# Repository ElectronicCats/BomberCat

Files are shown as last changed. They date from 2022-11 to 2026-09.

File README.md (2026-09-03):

# BomberCat

<p align=center>
<a href="https://github.com/ElectronicCats/BomberCat/wiki">
  
</a>
</p>

<p align=center>
<a href="https://electroniccats.com/store/bombercat/">
  
</a>
<a href="https://github.com/ElectronicCats/BomberCat/wiki">
  
</a>
</p>

<p align=center>
Also available at distributors:
</p>
<p align=center>
<a href="https://labs.ksec.co.uk/product-category/electronic-cat/">

</a>
</p>

BomberCat 💣 is the latest security tool that combines the most common card technologies: NFC technology (Near Field Communication) and magnetic stripe technology used in access control, identification, and banking cards.
Specially created to audit banking terminals, and identify NFC readers and sniffing tools, with this tool you can audit, read, or emulate magnetic stripes and NFC cards.

It also has an ESP32 co-processor with WiFiNINA firmware that allows it to make WiFi connections to use with HTTP or MQTT protocols, which will allow relay and spoofing attacks to be tested over long distances or on local web servers.

### Applications
BomberCat features an RP2040 MCU working along with the PN7150 (a recent generation NFC chip). 
The USB interface is provided by the RP2040 MCU and the NFC functionality is guaranteed by the PN7150.

BomberCat is designed to be intuitive for users. Easy to program using frameworks such as Arduino, Circuitpython, and Micropython.  We have prepared a series of examples with which you can start experimenting, check out the examples folder.

**Card emulation mode:** in which BomberCat behaves as a smart card or a tag. In this mode, BomberCat emulates an NFC tag. It does not initiate communication, it only responds to the NFC reader. 
A typical application of the card emulation mode is how people use NFC on their smartphones to replace several cards, badges, or tags at once (using the same smartphone for RFID access controls, contactless payments, etc). 
However, card emulation mode is not only beneficial for smartphones but any type of portable device.

**Read/Write:** in which BomberCat behaves as an NFC reader/writer. In this mode, BomberCat communicates with a passive tag, an NFC smart card, or an NFC device operating in the card emulation mode. It can read or write to a tag (although reading is a more common use case because tags will often be write-protected). In this mode, BomberCat generates an RF field, while a tag or card only modulates it.

**Magspoof:** for magnetic stripes interaction.
Magspoof mode can emulate magnetic stripe cards by emulating the electromagnetic pulses of this type of card.

## NFCGate relay

BomberCat can act as an [NFCGate](https://github.com/nfcgate/nfcgate)-compatible
**relay** endpoint: it pairs with a second NFCGate peer — another BomberCat or the
NFCGate Android app — through an `nfcgate-server`, relaying NFC APDUs over WiFi/TCP.
This makes a card that is physically in one place appear in front of a reader in
another — the classic test for whether a contactless reader accepts a card that is
not really present.

It ships with two pieces, each in its own repository:

- **Relay firmware** — [`bombercat-firmware`](https://github.com/ElectronicCats/bombercat-firmware),
  a role-selectable (`reader` / `card`) sketch built on the `BomberCatCore` library.
- **`bombercat` control CLI** — [`bombercat-tools`](https://github.com/ElectronicCats/bombercat-tools),
  a Python tool that configures, runs, monitors and captures the relay over
  USB-serial (APDU capture opens straight in Wireshark).

> Relay/spoofing features are for **authorized security audits only** — see the
> Disclaimer below.

## Characteristics:
- Cortex M0+ processor
- USB C 2.0
- NFC Reader, Card, and NFC Forum
- Arduino compatible
- 100% CircuitPython compatible
- UF2 Bootloader
- WIFI (WiFiNINA)
- BLE (ArduinoBLE)
- 1 LED status
- Open Hardware
- MagSpoof coil
- Battery
- RF protocols supported
  - NFCIP-1, NFCIP-2 protocol 
  - ISO/IEC 14443A, ISO/IEC 14443B PICC, NFC Forum T4T modes via host interface
  - NFC Forum T3T via host interface
  - ISO/IEC 14443A, ISO/IEC 14443B PCD designed according to NFC Forum digital protocol T4T platform and ISO-DEP 
  - FeliCa PCD mode
  - MIFARE Classic PCD encryption mechanism (MIFARE Classic 1K/4K)
  - NFC Forum tag 1 to 5 (MIFARE Ultralight, Jewel, Open FeliCa tag, MIFAREDESFire
  - ISO/IEC 15693/ICODE VCD mode 
  - Includes NXP ISO/IEC14443-A and Innovatron ISO/IEC14443-B intellectual property licensing rights

## Requirements

- **Arduino IDE:** version 2.3.3
- **Board Package:** Electronic Cats Mbed OS RP2040 Boards version 2.0.0

 Libraries:
 
  - **PubSubClient:** version 2.8.0
  - **WiFiNINA:** version 1.8.14
  - **Electronic Cats PN7150:** version 2.1.0
  - **SerialCommand:** [Arduino-SerialCommand](https://github.com/kroimon/Arduino-SerialCommand) 

### **Linux Setup Instructions**
If you are using Linux, ensure the BomberCat is properly recognized by running the post-install script located at:

`~/.arduino15/packages/electroniccats/hardware/mbed_rp2040/2.0.0/post_install.sh`

This step is essential to ensure the board can be detected and the firmware uploaded successfully.

## Wiki and Getting Started

[Getting Started in our Wiki](https://github.com/ElectronicCats/BomberCat/wiki)

## Repositories

This repository holds the **hardware** design (KiCad, BOM, mechanical files) and
general project documentation. Firmware and host tooling used to live here but were
split out into their own repositories for better version control and issue tracking:

### Firmware Repository
All BomberCat firmware (NFCGate relay, DetectTags, DetectReaders, magspoof, and more)
lives here:

https://github.com/ElectronicCats/bombercat-firmware

All BomberCat versions are supported in this repository — check which version you own
and select the proper branch to develop, build, or program your board.

### Tools Repository
The `bombercat` control CLI and other Python dev tooling live here:

https://github.com/ElectronicCats/bombercat-tools

## Disclaimer
>[!IMPORTANT]
>BomberCat is a wireless penetration testing tool intended **solely for use in authorized security audits, where such usage is permitted by applicable laws and regulations**. Before utilizing this tool, it is crucial to ensure compliance with all relevant legal requirements and obtain appropriate permissions from the relevant authorities.
>
>The board **does not provide** any means or authorization to utilize credit cards or engage in any financial transactions that are not legally authorized. **Electronic Cats holds no responsibility for any unauthorized use of the tool or any resulting damages**.

-------

## How to contribute 
 Contributions are welcome! 

Please read the document  [**Contribution Manual**](https://github.com/ElectronicCats/electroniccats-cla/blob/main/electroniccats-contribution-manual.md)  which will show you how to contribute your changes to the project.

✨ Thanks to all our [contributors](https://github.com/ElectronicCats/BomberCat/graphs/contributors)! ✨

See [**_Electronic Cats CLA_**](https://github.com/ElectronicCats/electroniccats-cla/blob/main/electroniccats-cla.md) for more information.

See the  [**community code of conduct**](https://github.com/ElectronicCats/electroniccats-cla/blob/main/electroniccats-community-code-of-conduct.md) for a vision of the community we want to build and what we expect from it.
 
### Supported by
 Thanks [Wallee](https://en.wallee.com/) for support this open source project
 
 <a href="https://en.wallee.com/">
  
</a>

## Maintainer

<p align=center>
<a href="https://github.com/sponsors/ElectronicCats">
  
</a>
</p>

Electronic Cats invests time and resources providing this open-source design, please support Electronic Cats and open-source hardware by purchasing products from Electronic Cats!

### License
<p>

</p>

Electronic Cats invests time and resources in providing this open-source design, please support Electronic Cats and open-source hardware by purchasing products from Electronic Cats!

Designed by Electronic Cats.

Firmware released under an GNU AGPL v3.0 license. See the LICENSE file for more information.

Hardware released under an CERN Open Hardware Licence v1.2. See the LICENSE_HARDWARE file for more information.

Electronic Cats is a registered trademark, please do not use if you sell these PCBs.

Jul 2022

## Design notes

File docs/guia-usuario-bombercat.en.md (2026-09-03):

# User Guide — BomberCat for NFC Audits

> **Read this in another language:** [Español](guia-usuario-bombercat.es.md)

---

## A. Introduction and Legal Warning

### What is BomberCat?

**BomberCat** is a security tool that works with contactless cards
(**NFC** — the same ones used for payments, access control, or identification)
and with magnetic stripe. With it, an auditor can **read, emulate, or relay**
a card to check whether a system is vulnerable.

This guide specifically covers the **relay** function: making a card that is
in one place "appear" in front of a reader that is somewhere else, joining the
two ends over WiFi. It is the classic test to demonstrate whether a reader
accepts a card that is not actually present.

> [!WARNING]
> ## ⚠️ LIABILITY NOTICE — READ IT BEFORE USING
>
> **BomberCat is designed EXCLUSIVELY for authorized security audits and
> testing in controlled environments.**
>
> - Use it **only** on systems, cards, and terminals that **belong to you** or
>   for which you have **explicit written permission** from the owner.
> - Using this tool on third-party cards, accounts, access credentials, or
>   terminals without authorization is, in most countries, a **crime**.
>
> > **The user is solely responsible for how they use the device and for any
> > legal, ethical, or other consequences that may arise from its misuse.**
>
> Electronic Cats and the authors of this firmware are **not responsible** for
> any unauthorized use or for the damages arising from it. The device does
> **not** authorize you to use credit cards or to carry out financial
> transactions that are not legally authorized.

**Before each test, make sure you have:**

- [ ] Written authorization from the owner of the system or the card.
- [ ] A defined scope (what is tested, when, and where).
- [ ] A controlled environment, without affecting third-party people or services.

---

## B. Specifications and Modes of Use

### What is always required? (for all three modes)

The relay always joins **two ends** through a small intermediary program
called the **NFCGate server**. One of the ends acts as a **reader** (reads a
real card) and the other as a **card** (presents itself to a terminal). No
matter which mode you choose: you always need these three pieces.

| Piece | What it is for |
|---|---|
| **NFCGate server** | A program that runs on a PC and forwards the data between the two ends. |
| **WiFi network** | The two ends and the server PC must be on the **same WiFi network**. |
| **Two ends** | One in *reader* mode and the other in *card* mode (depending on the chosen mode). |

**One-time installation of the control software (on your PC, only once):**

```sh
cd tools
python3 -m pip install -r requirements.txt   # installs the dependencies
python3 bombercat.py --help                  # checks that it works
```

> On Linux, for the PC to "see" the BomberCat over USB you may need to add
> your user to the `dialout` group:
> `sudo usermod -aG dialout $USER` and log back in.

**Start the NFCGate server (on the PC, before any test):**

```sh
bombercat testserver run              # starts the server, listens on port 5566
```

Leave it running in its own terminal window. Note the **IP address** of that
PC (for example `192.168.1.5`); you will need it to configure the ends.
On Windows/Mac/Linux you can see the IP with `ipconfig` or `ip a`.

> 💡 **On Linux**, the fastest way to find the IP of the computer running the
> server is the `hostname -I` command: it prints the machine's IP address(es)
> directly. The first one is usually the one for your WiFi network (the one
> you will put in `--server`, for example `192.168.1.5`).

**Key concepts that recur in every mode:**

- **Server (`--server`)**: the IP of the PC and the port, for example
  `192.168.1.5:5566`. **Both ends must point to the same server.**
- **Session (`--session`)**: a number from 1 to 255 that pairs the two ends.
  **Both ends must use exactly the same session number.**
- **Role (`--role`)**: `reader` (reads a physical card) or `card` (presents
  itself as a card to a terminal). **One end must be `reader` and the other `card`.**

> ℹ️ **About timing:** a relay transaction typically takes **12–15 seconds**.
> This is normal because of the WiFi + server path; it does not mean something
> is broken. Keep the card and the terminal still during that time.

---

### One-time preparation: flash the relay firmware onto the BomberCat

Every BomberCat you will use as an end (`reader` or `card`) needs the **NFCGate
relay firmware** flashed onto it. This is done **once** per device (or when a new
firmware version is released). If you bought the BomberCat with different firmware,
or you are not sure, follow these steps.

**What you need:**

- The BomberCat connected to your PC over USB-C.
- The [Arduino IDE](https://www.arduino.cc/en/software) 2.x **or** `arduino-cli`.
- The **Electronic Cats Mbed OS RP2040** board package and the **WiFiNINA** and
  **Electronic Cats PN7150** libraries (the Arduino IDE installs them from its
  board and library managers).

**With `arduino-cli` (the fastest way):**

```sh
cd firmware/NFCGate
arduino-cli compile -b electroniccats:mbed_rp2040:bombercat --library ../core .
arduino-cli upload  -b electroniccats:mbed_rp2040:bombercat -p /dev/ttyACM0 .
```

> Replace `/dev/ttyACM0` with your BomberCat's port (on Windows it will be
> something like `COM5`). The WiFiNINA *"architecture may be incompatible"*
> warnings are **normal** on the BomberCat, not an error.

**With the Arduino IDE:** open `firmware/NFCGate/NFCGate.ino`, select the board
**"Electronic Cats BomberCat"** and, so it resolves `#include <BomberCatCore.h>`,
create a link to the `firmware/core` folder inside `~/Arduino/libraries`. Then
click **Upload**.

**Check that it was flashed** (with the control software already installed):

```sh
bombercat device info      # should reply: fw 0.9.7, state idle
```

If it replies with the version and `state idle`, the BomberCat is ready. Repeat
the process on the **second** BomberCat if you are going to use Mode 1.

> The full technical details (pins, libraries, build options) are in
> [`firmware/NFCGate/README.md`](../firmware/NFCGate/README.md).

---

### Mode 1 — BomberCat Reader + BomberCat Card

**Purpose:** the most reliable and recommended mode. Two BomberCats: one reads
a physical card and the other presents it to a terminal, in another location,
over WiFi. Ideal for demonstrating an end-to-end relay without depending on a
phone. *(This mode is validated on hardware.)*

**Minimum requirements:**

- 2 BomberCat devices with the NFCGate relay firmware.
- 1 PC with the NFCGate server running (previous step).
- 1 physical card to read and 1 terminal/reader to test against.
- Everything on the same WiFi network.

**Steps:**

Connect **both** BomberCats over USB to the same PC. Each one gets a number
(`#1`, `#2`); you can see which is which with:

```sh
bombercat device list                # shows the connected BomberCats
bombercat identify -d 1              # blinks the LED of #1 to recognize it
```

1. **Configure the WiFi on both** (use your real network):
   ```sh
   bombercat config wifi -d 1 --ssid MyWiFiNetwork --pass 'mypassword'
   bombercat config wifi -d 2 --ssid MyWiFiNetwork --pass 'mypassword'
   ```
2. **Configure the roles** (one `reader`, the other `card`; **same session**):
   ```sh
   bombercat config nfcgate -d 1 --server 192.168.1.5:5566 --session 42 --role reader
   bombercat config nfcgate -d 2 --server 192.168.1.5:5566 --session 42 --role card
   ```
3. **Place the physical card** on BomberCat #1 (the `reader`).
4. **Start both**:
   ```sh
   bombercat run -d 1
   bombercat run -d 2
   ```
5. **Check that they connected**:
   ```sh
   bombercat status -d 1        # should show a link and a "peer" present
   ```
6. **Bring the terminal close** to BomberCat #2 (the `card`). Wait 12–15 s for
   the transaction to cross.
7. To see the live detail (logs and APDUs) while you test:
   ```sh
   bombercat monitor -d 1
   ```
8. **When finished**, stop both:
   ```sh
   bombercat stop -d 1
   bombercat stop -d 2
   ```

**Safety recommendations for this mode:**

- Keep the physical card **still and firmly resting** on the `reader`
  throughout the test; if it separates, the relay is cut off.
- Verify that both BomberCats are on the **same session**; a different number
  means they will never pair.
- Do not leave the BomberCats running unattended; stop them when done.

---

### Mode 2 — BomberCat Reader + Phone with NFCGate in Card mode

**Purpose:** use an Android phone with the **NFCGate** app as the end that
presents itself to the terminal (*card*/HCE mode), while the BomberCat reads a
physical card.

> [!IMPORTANT]
> ## 🔴 This mode requires a ROOTED phone
>
> Due to an Android limitation, a **normal (non-rooted)** phone **cannot**
> emulate a payment card toward a terminal: its card mode only responds to a
> test card, so the EMV terminal never reaches the app and **no data crosses**.
>
> This mode **only works** with a **rooted** phone that has the **native
> NFCGate module (Xposed / patched `nfcd`)** installed. If your phone is not
> rooted, **use Mode 3 instead** — it does the same thing with the roles
> reversed and works on normal phones.
>
> 📱 **Don't know how to root the phone or set up NFCGate?** Follow the
> [Guide to rooting an Android phone for NFCGate](https://github.com/ElectronicCats/bombercat-tools/blob/main/docs/guia-rooteo-android-nfcgate.en.md)
> (in the `bombercat-tools` repository), which explains step by step how to
> root with Magisk and install the NFCGate module (Zygisk + LSPosed), with
> their corresponding warnings.

**Minimum requirements:**

- 1 BomberCat with the relay firmware (it will be the `reader`).
- 1 **rooted** Android phone with the **NFCGate** app and its native module.
- 1 PC with the NFCGate server running.
- 1 physical card to read and 1 terminal to test against.
- Everything on the same WiFi network.

**Steps:**

1. **Configure the BomberCat as `reader`** (WiFi + server + session):
   ```sh
   bombercat config wifi    --ssid MyWiFiNetwork --pass 'mypassword'
   bombercat config nfcgate --server 192.168.1.5:5566 --session 42 --role reader
   ```
2. **On the phone, open the NFCGate app** and in its network settings enter
   **the same server address** (the PC's IP) and **the same session number** (42).
3. In the app, **choose emulation/card mode** (so the phone acts as the card
   in front of the terminal) and join the session.
4. **Place the physical card** on the BomberCat and start it:
   ```sh
   bombercat run
   bombercat status        # check that the "peer" (the phone) appears
   ```
5. **Bring the terminal close to the phone.** Wait 12–15 s for the transaction
   to cross.
6. **When finished**, `bombercat stop` and stop the relay in the app.

**Safety recommendations for this mode:**

- Confirm that the app shows the relay **active in emulation mode** before
  bringing the terminal close.
- A rooted phone is more vulnerable; use it dedicated to testing, not as your
  personal phone.
- If nothing crosses, it is almost always because the phone **is not rooted**
  or the NFCGate module is not active → switch to **Mode 3**.

---

### Mode 3 — BomberCat Card + Phone with NFCGate in Reader mode

**Purpose:** the equivalent of Mode 2 but **compatible with normal
(non-rooted) phones**. Here the phone acts as the **reader** (reads a physical
card with its NFC) and the BomberCat presents itself as a **card** to the
terminal. This is the recommended way if you want to use a phone.

**Minimum requirements:**

- 1 BomberCat with the relay firmware (it will be the `card`).
- 1 **normal** Android phone with the **NFCGate** app (no root required).
- 1 PC with the NFCGate server running.
- 1 physical card (the phone will read it) and 1 terminal to test against.
- Everything on the same WiFi network.

**Steps:**

1. **Configure the BomberCat as `card`** (WiFi + server + session):
   ```sh
   bombercat config wifi    --ssid MyWiFiNetwork --pass 'mypassword'
   bombercat config nfcgate --server 192.168.1.5:5566 --session 42 --role card
   ```
2. **On the phone, open NFCGate**, enter **the same server address** and **the
   same session number** (42), and **choose reader mode**. Join the session.
3. **Bring the physical card close to the phone** (the phone is the one
   reading it).
4. **Start the BomberCat**:
   ```sh
   bombercat run
   bombercat status        # check that the "peer" (the phone) appears
   ```
5. **Bring the terminal close to the BomberCat.** Wait 12–15 s for the
   transaction to cross. To see the live detail:
   ```sh
   bombercat monitor
   ```
6. **When finished**, `bombercat stop` and stop the relay in the app.

**Safety recommendations for this mode:**

- Keep the physical card **firmly resting on the phone** during the test.
- As in the other modes, verify that **server and session match** on both ends.
- It is the preferred mode for demonstrations with a phone because it does not
  require root.

---

## C. Common Troubleshooting

| Problem | Likely cause | Solution |
|---|---|---|
| **No data crosses between the ends** | Different session on each end, or they point to different servers. | Check that `--session` and `--server` are **identical** on both ends. |
| **`bombercat device list` does not show the BomberCat** | Charge-only USB cable, or missing serial port permission (Linux). | Use a **data** cable; on Linux add your user to the `dialout` group and log back in. |
| **`status` never shows a "peer"** | The other end has not joined, or there is no WiFi. | Confirm that the server is running, that both ends are on the **same WiFi**, and that you started both (`run`). |
| **With the phone in card mode (Mode 2) nothing happens** | The phone **is not rooted** (Android HCE limitation). | Use **Mode 3**, which works on normal phones. |
| **The transaction takes "too long" (10–15 s)** | This is the normal time for the WiFi + server path. | It is not a failure: keep the card and terminal **still** until it finishes. |
| **The relay cuts off midway** | The card separated from the reader, or the WiFi dropped. | Rest the card again; move the devices closer to the router; `run` again. |

---

## D. Glossary of Terms

- **NFC (Near Field Communication):** contactless communication technology at a
  few centimeters. It is what "contactless" payment cards, card-based access,
  and mobile payment use.
- **Card / Emulation (HCE):** making a device **behave like a card** in front
  of a reader. On a phone it is called *HCE* (Host Card Emulation).
- **Reader:** the role of the one that **reads** a card (generates the NFC
  field and asks it questions). The payment terminal is a reader.
- **Terminal / PoS:** the device that charges or validates (for example, a
  store terminal or an access-control reader).
- **Relay:** a technique that **forwards** the conversation between a card and
  a reader that are **in different places**, as if they were together. It is
  what BomberCat does in this guide.
- **Replay:** replaying a previously captured communication. Related, but not
  what this flow does (here the forwarding is **live**).
- **Security audit:** an **authorized** test to find out whether a system is
  vulnerable, with the owner's permission and within an agreed scope.
- **APDU:** each "message" exchanged between card and reader. In the monitor
  you will see them as sequences of bytes in hexadecimal.
- **NFCGate server:** the intermediary program that forwards the data between
  the two ends of the relay over the network.
- **Session:** a number (1–255) that **pairs** the two ends on the server.
  Both must use the same one.
- **Role:** the part played by each end: `reader` (reads a physical card) or
  `card` (presents itself as a card to a terminal).
- **Firmware:** the internal program of the BomberCat. Here, the NFCGate-
  compatible relay firmware.
- **NFCGate:** an Android project/app for capturing and relaying NFC, with
  which the BomberCat is compatible.

---

> **Final reminder:** use BomberCat only in **authorized** tests. The
> responsibility for its use is **entirely yours**.

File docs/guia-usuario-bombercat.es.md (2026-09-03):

# Guía de Uso — BomberCat para Auditorías NFC

> **Read this in another language:** [English](guia-usuario-bombercat.en.md)

---

## A. Introducción y Advertencia Legal

### ¿Qué es BomberCat?

**BomberCat** es una herramienta de seguridad que trabaja con tarjetas sin
contacto (**NFC** — las mismas de pagos, control de acceso o identificación) y
con banda magnética. Con ella un auditor puede **leer, emular o retransmitir
(_relay_)** una tarjeta para comprobar si un sistema es vulnerable.

Esta guía cubre en concreto la función de **relay**: hacer que una tarjeta que
está en un lugar "aparezca" frente a un lector que está en otro, uniendo los dos
extremos por WiFi. Es la prueba clásica para demostrar si un lector acepta una
tarjeta que en realidad no está presente.

> [!WARNING]
> ## ⚠️ AVISO DE RESPONSABILIDAD — LÉELO ANTES DE USAR
>
> **BomberCat está diseñada EXCLUSIVAMENTE para auditorías de seguridad
> autorizadas y pruebas en entornos controlados.**
>
> - Úsala **solo** sobre sistemas, tarjetas y terminales que **te pertenecen** o
>   para los que tienes **permiso explícito y por escrito** del propietario.
> - Usar esta herramienta sobre tarjetas, cuentas, accesos o terminales de
>   terceros sin autorización es, en la mayoría de los países, un **delito**.
>
> > **El usuario es el único responsable del uso que dé al dispositivo y de las
> > consecuencias legales, éticas o de cualquier otra índole que pudieran
> > derivarse de su uso indebido.**
>
> Electronic Cats y los autores de este firmware **no se hacen responsables** de
> ningún uso no autorizado ni de los daños que de él se deriven. El dispositivo
> **no** te autoriza a usar tarjetas de crédito ni a realizar transacciones
> financieras no autorizadas legalmente.

**Antes de cada prueba, asegúrate de tener:**

- [ ] Autorización por escrito del propietario del sistema o de la tarjeta.
- [ ] Un alcance definido (qué se prueba, cuándo y dónde).
- [ ] Un entorno controlado, sin afectar a personas o servicios de terceros.

---

## B. Especificaciones y Modos de Uso

### ¿Qué hace falta siempre? (para los tres modos)

El relay siempre une **dos extremos** a través de un pequeño programa
intermediario llamado **servidor NFCGate**. Uno de los extremos actúa como
**lector** (lee una tarjeta real) y el otro como **tarjeta** (se presenta ante un
terminal). Da igual qué modo elijas: siempre necesitas estas tres piezas.

| Pieza | Para qué sirve |
|---|---|
| **Servidor NFCGate** | Un programa que corre en una PC y reenvía los datos entre los dos extremos. |
| **Red WiFi** | Los dos extremos y la PC del servidor deben estar en la **misma red WiFi**. |
| **Dos extremos** | Uno en modo *lector* y otro en modo *tarjeta* (según el modo elegido). |

**Instalación única del software de control (en tu PC, una sola vez):**

```sh
cd tools
python3 -m pip install -r requirements.txt   # instala las dependencias
python3 bombercat.py --help                  # comprueba que funciona
```

> En Linux, para que la PC "vea" la BomberCat por USB puede que necesites añadir
> tu usuario al grupo `dialout`:
> `sudo usermod -aG dialout $USER` y volver a iniciar sesión.

**Arrancar el servidor NFCGate (en la PC, antes de cualquier prueba):**

```sh
bombercat testserver run              # arranca el servidor, escucha en el puerto 5566
```

Déjalo corriendo en su propia ventana de terminal. Anota la **dirección IP** de
esa PC (por ejemplo `192.168.1.5`); la necesitarás para configurar los extremos.
En Windows/Mac/Linux puedes ver la IP con `ipconfig` o `ip a`.

> 💡 **En Linux**, la forma más rápida de saber la IP de la computadora que corre
> el servidor es el comando `hostname -I`: imprime directamente la(s) dirección(es)
> IP del equipo. La primera suele ser la de tu red WiFi (la que pondrás en
> `--server`, por ejemplo `192.168.1.5`).

**Conceptos clave que se repiten en todos los modos:**

- **Servidor (`--server`)**: la IP de la PC y el puerto, por ejemplo
  `192.168.1.5:5566`. **Los dos extremos deben apuntar al mismo servidor.**
- **Sesión (`--session`)**: un número del 1 al 255 que empareja los dos extremos.
  **Los dos extremos deben usar exactamente el mismo número de sesión.**
- **Rol (`--role`)**: `reader` (lee una tarjeta física) o `card` (se presenta como
  tarjeta ante un terminal). **Un extremo debe ser `reader` y el otro `card`.**

> ℹ️ **Sobre los tiempos:** una transacción por relay tarda típicamente
> **12–15 segundos**. Es normal por el camino WiFi + servidor; no significa que
> algo esté roto. Mantén la tarjeta y el terminal quietos durante ese tiempo.

---

### Preparación única: grabar el firmware de relay en la BomberCat

Cada BomberCat que vayas a usar como extremo (`reader` o `card`) necesita tener
grabado el **firmware de relay NFCGate**. Esto se hace **una sola vez** por
dispositivo (o cuando salga una versión nueva del firmware). Si compraste la
BomberCat con otro firmware, o no estás seguro, sigue estos pasos.

**Qué necesitas:**

- La BomberCat conectada por USB-C a tu PC.
- El [Arduino IDE](https://www.arduino.cc/en/software) 2.x **o** `arduino-cli`.
- El paquete de placas **Electronic Cats Mbed OS RP2040** y las librerías
  **WiFiNINA** y **Electronic Cats PN7150** (el Arduino IDE las instala desde su
  gestor de placas y de librerías).

**Con `arduino-cli` (lo más rápido):**

```sh
cd firmware/NFCGate
arduino-cli compile -b electroniccats:mbed_rp2040:bombercat --library ../core .
arduino-cli upload  -b electroniccats:mbed_rp2040:bombercat -p /dev/ttyACM0 .
```

> Sustituye `/dev/ttyACM0` por el puerto de tu BomberCat (en Windows será algo
> como `COM5`). Los avisos de WiFiNINA *"architecture may be incompatible"* son
> **normales** en la BomberCat, no son un error.

**Con el Arduino IDE:** abre `firmware/NFCGate/NFCGate.ino`, selecciona la placa
**"Electronic Cats BomberCat"** y, para que resuelva `#include <BomberCatCore.h>`,
crea un enlace de la carpeta `firmware/core` dentro de `~/Arduino/libraries`.
Después pulsa **Subir**.

**Comprueba que quedó grabado** (con el software de control ya instalado):

```sh
bombercat device info      # debe responder: fw 0.9.7, state idle
```

Si responde con la versión y `state idle`, la BomberCat está lista. Repite el
proceso en la **segunda** BomberCat si vas a usar el Modo 1.

> Los detalles técnicos completos (pines, librerías, opciones de compilación)
> están en [`firmware/NFCGate/README.md`](../firmware/NFCGate/README.md).

---

### Modo 1 — BomberCat Reader + BomberCat Card

**Propósito:** el modo más fiable y recomendado. Dos BomberCat: una lee una
tarjeta física y la otra la presenta a un terminal, en otro lugar, a través del
WiFi. Ideal para demostrar un relay de principio a fin sin depender de un
teléfono. *(Este modo está validado en hardware.)*

**Requisitos mínimos:**

- 2 dispositivos BomberCat con el firmware de relay NFCGate.
- 1 PC con el servidor NFCGate corriendo (paso anterior).
- 1 tarjeta física a leer y 1 terminal/lector contra el que probar.
- Todo en la misma red WiFi.

**Pasos:**

Conecta **ambas** BomberCat por USB a la misma PC. Cada una recibe un número
(`#1`, `#2`); puedes ver cuáles son con:

```sh
bombercat device list                # muestra las BomberCat conectadas
bombercat identify -d 1              # parpadea el LED de la #1 para reconocerla
```

1. **Configura el WiFi en las dos** (usa tu red real):
   ```sh
   bombercat config wifi -d 1 --ssid MiRedWiFi --pass 'miclave'
   bombercat config wifi -d 2 --ssid MiRedWiFi --pass 'miclave'
   ```
2. **Configura los roles** (una `reader`, la otra `card`; **misma sesión**):
   ```sh
   bombercat config nfcgate -d 1 --server 192.168.1.5:5566 --session 42 --role reader
   bombercat config nfcgate -d 2 --server 192.168.1.5:5566 --session 42 --role card
   ```
3. **Coloca la tarjeta física** sobre la BomberCat #1 (la `reader`).
4. **Arranca las dos**:
   ```sh
   bombercat run -d 1
   bombercat run -d 2
   ```
5. **Comprueba que se conectaron**:
   ```sh
   bombercat status -d 1        # debe indicar enlace y "peer" presente
   ```
6. **Acerca el terminal** a la BomberCat #2 (la `card`). Espera 12–15 s a que
   cruce la transacción.
7. Para ver el detalle en vivo (registros y APDUs) mientras pruebas:
   ```sh
   bombercat monitor -d 1
   ```
8. **Al terminar**, detén ambas:
   ```sh
   bombercat stop -d 1
   bombercat stop -d 2
   ```

**Recomendaciones de seguridad para este modo:**

- Mantén la tarjeta física **quieta y bien apoyada** sobre la `reader` durante
  toda la prueba; si se separa, el relay se corta.
- Verifica que ambas BomberCat estén en la **misma sesión**; un número distinto
  hace que nunca se emparejen.
- No dejes las BomberCat arrancadas sin supervisión; detenlas al acabar.

---

### Modo 2 — BomberCat Reader + Móvil con NFCGate en modo Card

**Propósito:** usar un teléfono Android con la app **NFCGate** como el extremo que
se presenta ante el terminal (modo *tarjeta*/HCE), mientras la BomberCat lee una
tarjeta física.

> [!IMPORTANT]
> ## 🔴 Este modo requiere un teléfono ROOTEADO
>
> Por una limitación de Android, un teléfono **normal (sin root)** **no puede**
> emular una tarjeta de pago hacia un terminal: su modo tarjeta solo responde a
> una tarjeta de prueba, así que el terminal EMV nunca llega a la app y **no
> cruza ningún dato**.
>
> Este modo **solo funciona** con un teléfono **rooteado** que tenga instalado el
> **módulo nativo de NFCGate (Xposed / `nfcd` parcheado)**. Si tu teléfono no está
> rooteado, **usa el Modo 3 en su lugar** — hace lo mismo con los roles
> invertidos y funciona en teléfonos normales.
>
> 📱 **¿No sabes cómo rootear el teléfono ni preparar NFCGate?** Sigue la
> [Guía para rootear un teléfono Android para NFCGate](https://github.com/ElectronicCats/bombercat-tools/blob/main/docs/guia-rooteo-android-nfcgate.es.md)
> (en el repositorio `bombercat-tools`), que explica paso a paso el rooteo con
> Magisk y la instalación del módulo de NFCGate (Zygisk + LSPosed), con sus
> advertencias correspondientes.

**Requisitos mínimos:**

- 1 BomberCat con el firmware de relay (será el `reader`).
- 1 teléfono Android **rooteado** con la app **NFCGate** y su módulo nativo.
- 1 PC con el servidor NFCGate corriendo.
- 1 tarjeta física a leer y 1 terminal contra el que probar.
- Todo en la misma red WiFi.

**Pasos:**

1. **Configura la BomberCat como `reader`** (WiFi + servidor + sesión):
   ```sh
   bombercat config wifi    --ssid MiRedWiFi --pass 'miclave'
   bombercat config nfcgate --server 192.168.1.5:5566 --session 42 --role reader
   ```
2. **En el teléfono, abre la app NFCGate** y en sus ajustes de red pon **la misma
   dirección del servidor** (la IP de la PC) y **el mismo número de sesión** (42).
3. En la app, **elige el modo emulación/tarjeta** (que el teléfono actúe como la
   tarjeta ante el terminal) y únete a la sesión.
4. **Coloca la tarjeta física** sobre la BomberCat y arráncala:
   ```sh
   bombercat run
   bombercat status        # comprueba que aparece el "peer" (el teléfono)
   ```
5. **Acerca el terminal al teléfono.** Espera 12–15 s a que cruce la transacción.
6. **Al terminar**, `bombercat stop` y detén el relay en la app.

**Recomendaciones de seguridad para este modo:**

- Confirma que la app muestra el relay **activo en modo emulación** antes de
  acercar el terminal.
- Un teléfono rooteado es más vulnerable; úsalo dedicado a pruebas, no como tu
  teléfono personal.
- Si no cruza nada, casi siempre es porque el teléfono **no está rooteado** o el
  módulo NFCGate no está activo → cambia al **Modo 3**.

---

### Modo 3 — BomberCat Card + Móvil con NFCGate en modo Reader

**Propósito:** el equivalente al Modo 2 pero **compatible con teléfonos normales
(sin root)**. Aquí el teléfono actúa como **lector** (lee una tarjeta física con
su NFC) y la BomberCat se presenta como **tarjeta** ante el terminal. Es la forma
recomendada si quieres usar un teléfono.

**Requisitos mínimos:**

- 1 BomberCat con el firmware de relay (será la `card`).
- 1 teléfono Android **normal** con la app **NFCGate** (no requiere root).
- 1 PC con el servidor NFCGate corriendo.
- 1 tarjeta física (la leerá el teléfono) y 1 terminal contra el que probar.
- Todo en la misma red WiFi.

**Pasos:**

1. **Configura la BomberCat como `card`** (WiFi + servidor + sesión):
   ```sh
   bombercat config wifi    --ssid MiRedWiFi --pass 'miclave'
   bombercat config nfcgate --server 192.168.1.5:5566 --session 42 --role card
   ```
2. **En el teléfono, abre NFCGate**, pon **la misma dirección del servidor** y **el
   mismo número de sesión** (42), y **elige el modo lector**. Únete a la sesión.
3. **Acerca la tarjeta física al teléfono** (el teléfono es quien la lee).
4. **Arranca la BomberCat**:
   ```sh
   bombercat run
   bombercat status        # comprueba que aparece el "peer" (el teléfono)
   ```
5. **Acerca el terminal a la BomberCat.** Espera 12–15 s a que cruce la
   transacción. Para ver el detalle en vivo:
   ```sh
   bombercat monitor
   ```
6. **Al terminar**, `bombercat stop` y detén el relay en la app.

**Recomendaciones de seguridad para este modo:**

- Mantén la tarjeta física **bien apoyada sobre el teléfono** durante la prueba.
- Como en los demás modos, verifica que **servidor y sesión coinciden** en los dos
  extremos.
- Es el modo preferente para demostraciones con teléfono por no requerir root.

---

## C. Solución de Problemas Comunes

| Problema | Causa probable | Solución |
|---|---|---|
| **No cruza ningún dato entre extremos** | Sesión distinta en cada extremo, o apuntan a servidores distintos. | Revisa que `--session` y `--server` sean **idénticos** en los dos extremos. |
| **`bombercat device list` no muestra la BomberCat** | Cable USB de solo carga, o falta permiso de puerto serie (Linux). | Usa un cable de **datos**; en Linux añade tu usuario al grupo `dialout` y reinicia sesión. |
| **`status` nunca muestra "peer"** | El otro extremo no se ha unido, o no hay WiFi. | Confirma que el servidor está corriendo, que ambos extremos están en la **misma WiFi** y que arrancaste los dos (`run`). |
| **Con teléfono en modo tarjeta (Modo 2) no pasa nada** | El teléfono **no está rooteado** (limitación de Android HCE). | Usa el **Modo 3**, que funciona en teléfonos normales. |
| **La transacción tarda "demasiado" (10–15 s)** | Es el tiempo normal del camino WiFi + servidor. | No es un fallo: mantén tarjeta y terminal **quietos** hasta que termine. |
| **El relay se corta a mitad** | La tarjeta se separó del lector, o se cayó el WiFi. | Vuelve a apoyar la tarjeta; acerca los equipos al router; vuelve a `run`. |

---

## D. Glosario de Términos

- **NFC (Near Field Communication):** tecnología de comunicación sin contacto a
  pocos centímetros. Es lo que usan las tarjetas de pago "contactless", los
  accesos por tarjeta y el pago con el móvil.
- **Tarjeta / Emulación (HCE):** hacer que un dispositivo **se comporte como una
  tarjeta** ante un lector. En un teléfono se llama *HCE* (Host Card Emulation).
- **Lector (Reader):** el papel de quien **lee** una tarjeta (genera el campo NFC
  y le hace preguntas). El terminal de pago es un lector.
- **Terminal / PoS:** el aparato que cobra o valida (por ejemplo, la terminal de
  un comercio o un lector de control de acceso).
- **Relay (retransmisión):** técnica que **reenvía** la conversación entre una
  tarjeta y un lector que están **en lugares distintos**, como si estuvieran
  juntos. Es lo que hace BomberCat en esta guía.
- **Replay:** reproducir una comunicación capturada previamente. Relacionado, pero
  no es lo que hace este flujo (aquí el reenvío es **en vivo**).
- **Auditoría de seguridad:** prueba **autorizada** para descubrir si un sistema
  es vulnerable, con permiso del propietario y dentro de un alcance acordado.
- **APDU:** cada "mensaje" que se intercambian tarjeta y lector. En el monitor los
  verás como secuencias de bytes en hexadecimal.
- **Servidor NFCGate:** el programa intermediario que reenvía los datos entre los
  dos extremos del relay por la red.
- **Sesión:** número (1–255) que **empareja** a los dos extremos en el servidor.
  Ambos deben usar el mismo.
- **Rol:** el papel de cada extremo: `reader` (lee una tarjeta física) o `card`
  (se presenta como tarjeta ante un terminal).
- **Firmware:** el programa interno de la BomberCat. Aquí, el firmware de relay
  compatible con NFCGate.
- **NFCGate:** proyecto/app de Android para capturar y retransmitir NFC, con el que
  la BomberCat es compatible.

---

> **Recordatorio final:** usa BomberCat solo en pruebas **autorizadas**. La
> responsabilidad del uso es **exclusivamente tuya**.

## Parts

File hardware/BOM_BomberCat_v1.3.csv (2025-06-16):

Value | Reference | Footprint | LCSC# | Qty | DNP | manf#
ABM8-272-T3 | Y3 | Crystal:Crystal_SMD_Abracon_ABM8G-4Pin_3.2x2.5mm | C20625731 | 1
27.12Mhz | Y1 | Crystal:Crystal_SMD_2016-4Pin_2.0x1.6mm | C252276 | 1 |  | 520-271.2-6-37-JTNT
TC4424 | U7 | Package_SO:SOIC-8_3.9x4.9mm_P1.27mm | C7498963 | 1 |  | TC4424AVOA
W25Q16JV | U6 | BomberCat:SON50P200X300X40-9N | C2843335 | 1 |  | W25Q16JVUUIQ
ESP32-WROOM-32D | U5 | RF_Module:ESP32-WROOM-32 | C473012 | 1 |  | ESP32M4
AP2112K-3.3 | U4 | Package_TO_SOT_SMD:SOT-23-5 | C150742 | 1 |  | AP7365-33WG-7
MCP73831T-2DCI/OT | U3 | Package_TO_SOT_SMD:SOT-23-5 | C424093 | 1 |  | MCP73831T-2DCI/OT
RP2040 | U2 | BomberCat:RP2040-QFN-56 | C2040 | 1 |  | RP2040
PN7150B0HN_C11006Y-PN7150B0HN_C11006Y | U1 | Package_DFN_QFN:QFN-40-1EP_6x6mm_P0.5mm_EP4.6x4.6mm | C702907 | 1 |  | PN7150B0HN/C11002Y
SOURCE MAG | SW4 | BomberCat:JS202011CQN | C221663 | 1 |  | JS202011CQN
ON | SW3 | BomberCat:JS102011SAQN | C221660 | 1 |  | JS102011SAQN
GPIO | SW2 | Button_Switch_SMD:SW_SPST_TL3342 | C318884 | 1
RESET | SW1 | Button_Switch_SMD:SW_SPST_TL3342 | C318884 | 1
3.24R | R18,R19 | Resistor_SMD:R_0603_1608Metric | C166817 | 2 |  | RC0603FR-073R4
2k2 | R15,R16 | Resistor_SMD:R_0603_1608Metric | C113303 | 2 |  | RC0603JR-072K2L
27 | R9,R10 | Resistor_SMD:R_0603_1608Metric | C403464 | 2 |  | ERJ3GEYJ270V
100K | R6,R7,R14,R21,R22 | Resistor_SMD:R_0603_1608Metric | C15458 | 5
5k1 | R4,R5,R8 | Resistor_SMD:R_0603_1608Metric | C23186 | 3
1K | R3,R11,R12,R13 | Resistor_SMD:R_0603_1608Metric | C112433 | 4 |  | WR06X1001FTL
10K | R1,R2,R17,R20 | Resistor_SMD:R_0603_1608Metric | C2930027 | 4
DMG3415U-7 | Q1 | Package_TO_SOT_SMD:SOT-23 | C96616 | 1 |  | DMG3415U-7
USB_C_Plug_USB2.0 | P1 | Connectors:C393939 | C393939 | 1
30t_30mm | L4 | BomberCat:Coil_30t_30mm_0.2_0.2_0.6_0.3 |  | 1 | DNP
L | L3 | Connectors:MOLEX_1661 | C22418213 | 1 |  | CONUFL001-SMD-T
160nH | L1,L2 | Inductor_SMD:L_0603_1608Metric_Pad1.05x0.95mm_HandSolder | C434822 | 2 |  | MLJ1608WR16JT000
MAGSPOOF | J3,J4 | Connector_PinHeader_2.54mm:PinHeader_1x02_P2.54mm_Vertical |  | 2 | DNP
Battery | J1 | Connector_PinHeader_2.54mm:PinHeader_1x02_P2.54mm_Vertical | - | 1 | DNP | -
MountingHole | H1,H2,H3,H4 | MountingHole:MountingHole_2.2mm_M2 | - | 4 | DNP | -
0.5A | F1 | Fuse:Fuse_0805_2012Metric | C2649565 | 1 |  | MFU0805FF00500P100
MBR120 | D4 | Diode_SMD:D_SOD-123F | C130880 | 1 |  | MBR120LSF
LED | D1,D2,D3 | LED_SMD:LED_0805_2012Metric_Pad1.15x1.40mm_HandSolder | C965815 | 3 |  | XL-2012UGC
15pF | C35,C36 | Capacitor_SMD:C_0603_1608Metric | C107037 | 2
120pF | C30,C31 | Capacitor_SMD:C_0603_1608Metric | C107035 | 2 |  | CC0603JRNPO9BN121
10uF | C29,C34 | Capacitor_SMD:C_0603_1608Metric | C96446 | 2 |  | CL10A106MA8NRNC
100pF/50V | C27,C28 | Capacitor_SMD:C_0603_1608Metric | C14665 | 2 |  | 06035A101JAT4A
680pF | C25,C26 | Capacitor_SMD:C_0603_1608Metric | C107055 | 2 |  | 885012206107
1nF/16V | C23,C24 | Capacitor_SMD:C_0603_1608Metric | C519403 | 2
10uF | C11,C22 | Capacitor_SMD:C_0603_1608Metric | C85713 | 2
1uF | C10,C14 | Capacitor_SMD:C_0603_1608Metric | C15849 | 2
100nF | C7,C9,C12,C13,C15,C16,C17,C18,C19,C20,C21,C32,C33 | Capacitor_SMD:C_0603_1608Metric | C282519 | 13
1uF | C5,C6,C8 | Capacitor_SMD:C_0603_1608Metric | C5673 | 3
10pF | C3,C4 | Capacitor_SMD:C_0603_1608Metric | C106245 | 2 |  | CC0603JRNPO9BN100

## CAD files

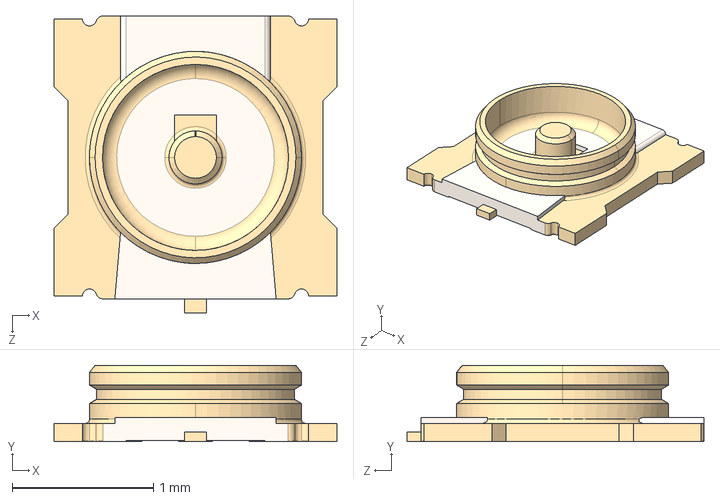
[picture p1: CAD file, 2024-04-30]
hardware/3D_Files/I-PEX MHF_7 Recepticle.STEP
2.00 x 0.54 x 2.10 mm

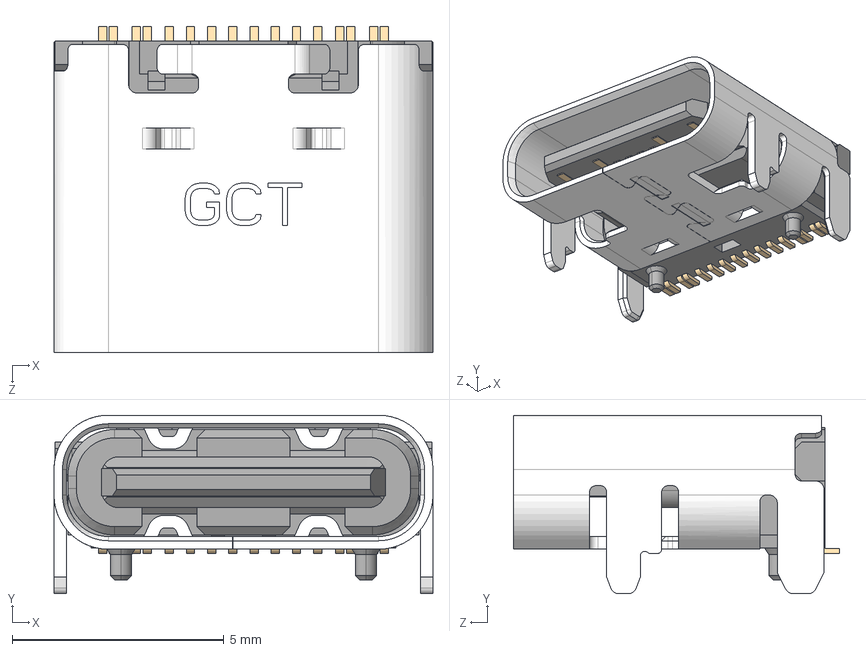
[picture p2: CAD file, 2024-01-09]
hardware/3D_Files/USB4105-GF-A.stp
8.94 x 4.21 x 7.70 mm
HSG_默认

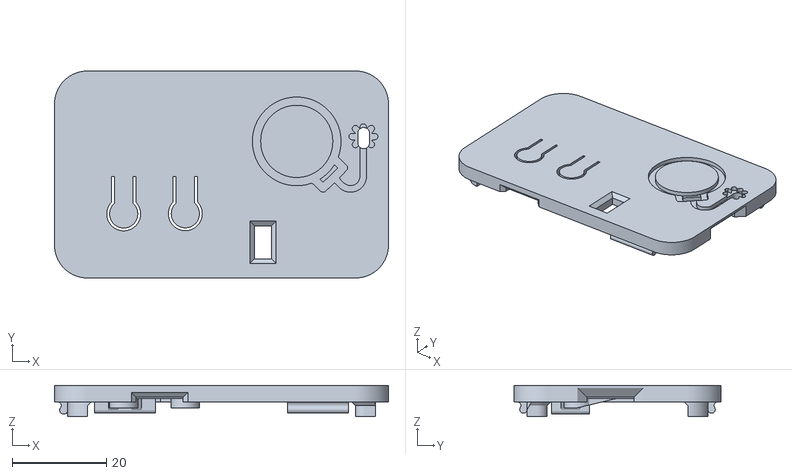
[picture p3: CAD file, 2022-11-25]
hardware/3D_Files/Top_noLogo.stl
71.0 x 44.0 x 6.60

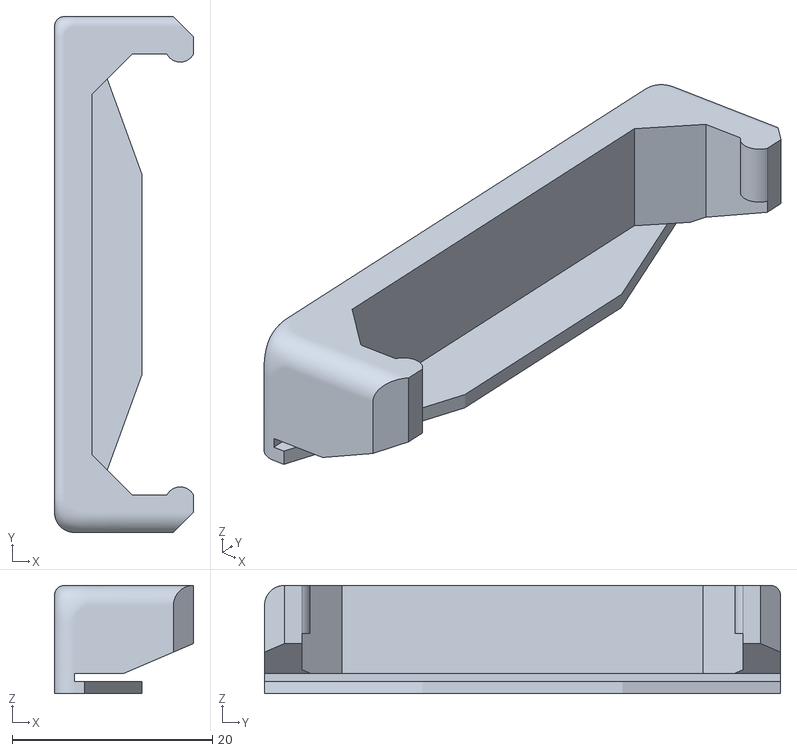
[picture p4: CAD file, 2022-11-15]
hardware/3D_Files/Card_holder.stl
13.9 x 51.5 x 10.8

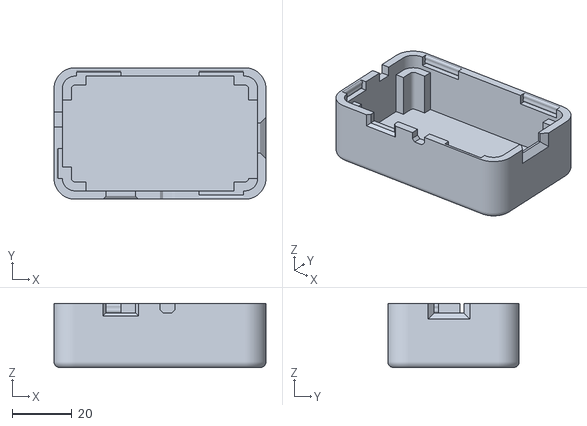
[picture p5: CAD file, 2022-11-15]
hardware/3D_Files/Bottom_client.stl
71.0 x 44.0 x 21.5

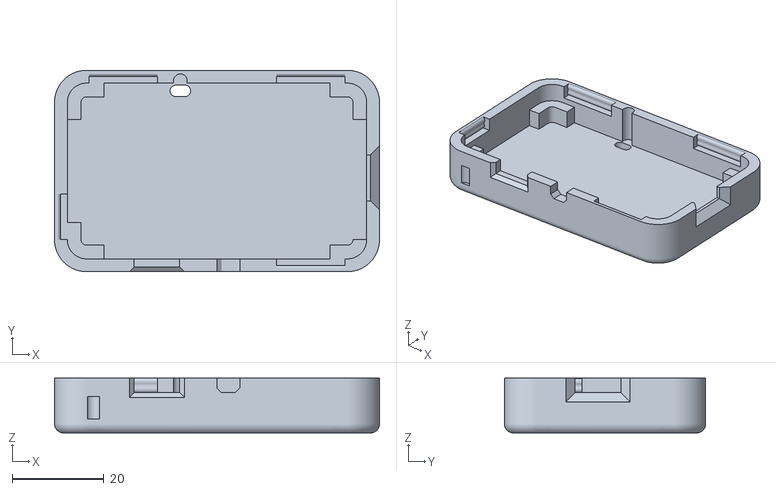
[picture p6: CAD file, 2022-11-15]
hardware/3D_Files/Bottom_host.stl
71.0 x 44.0 x 12.0

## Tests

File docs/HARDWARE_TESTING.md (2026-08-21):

# Prueba en hardware — NFCGate relay (Fase 7)

Guía para probar el relay NFCGate en placa real, **desde cero**: cómo flashear con
[`scripts/flash_bombercat.sh`](../scripts/flash_bombercat.sh) y luego dos caminos
completos, explícitos y paso a paso:

- **Camino A —** relay con **dos BomberCat**.
- **Camino B —** relay con **una BomberCat + la app Android NFCGate** como el otro extremo.

> Estado (2026-08-17): **probado en hardware real (Camino A, dos BomberCat), con
> transacciones consecutivas.** El relay cursa transacciones EMV completas de
> extremo a extremo, una tras otra sin colgarse (~12 s cada una; mantén el terminal
> sobre el `card` ese tiempo). Débito Mastercard real sobre el `reader`, teléfono
> con app lectora EMV sobre el `card`. Dos bugs de la ruta RF ya se corrigieron: la
> activación/re-arme de la emulación
> (resuelto) y el enlace TCP half-open que colgaba la 2ª transacción
> (corregido — reflashea el firmware para tenerlo). **Reflashea siempre la última
> versión** antes de probar. Si algo no cuadra, captura la salida de
> `bombercat monitor` para depurar. *(Camino B contra la app NFCGate Android:
> **variante B2** —BomberCat `card` + móvil lector— **probada OK**; **variante B1**
> —BomberCat `reader` + móvil emulador— **probada OK con un móvil ROOTEADO**
> (2026-08-19, Motorola Edge 20 Pro): imposible en móvil stock, requiere root +
> Xposed + hook nativo de NFCGate..)*

---

## Parte 0 — Flashear el firmware (con `flash_bombercat.sh`)

Un solo sketch sirve para **ambos roles**: **`firmware/NFCGate/`**. El rol (reader
o card) se elige luego por CLI, **no recompilando**. Flashea el mismo firmware en
cada BomberCat que uses (en el Camino B, solo en tu única placa).

El script [`scripts/flash_bombercat.sh`](../scripts/flash_bombercat.sh) hace todo el
trabajo pesado: instala `arduino-cli` si falta, el core
`electroniccats:mbed_rp2040`, las librerías necesarias, compila y sube el
firmware (por puerto serie o copiando el `.uf2` si la placa está en modo
bootloader).

### 0.1 — Primera vez: preparar el toolchain

Desde la **raíz del repo**:

```sh
chmod +x scripts/flash_bombercat.sh     # solo la primera vez, si hace falta
./scripts/flash_bombercat.sh --setup    # instala core + librerías y termina
```

En **Linux**, el `--setup` te imprimirá un comando `sudo …/post_install.sh` para
las reglas udev del bootloader RP2040. Ejecútalo si aún no lo has hecho. Además,
tu usuario debe estar en el grupo `dialout` para abrir el puerto serie sin sudo:

```sh
sudo usermod -aG dialout $USER   # luego cierra sesión y vuelve a entrar
```

### 0.2 — Flashear la placa

Conecta **una** BomberCat por USB (flashea de una en una) y ejecuta:

```sh
./scripts/flash_bombercat.sh -f NFCGate          # compila y flashea NFCGate
./scripts/flash_bombercat.sh -f NFCGate -m       # …y abre el monitor serie al terminar
```

El script detecta la placa solo:

- Si aparece como puerto serie normal (`/dev/ttyACM0`), hace el reset a 1200 bps y sube el binario.
- Si la pones en **modo bootloader** (doble reset → aparece la unidad `RPI-RP2`), copia el `.uf2`.
- ¿No la detecta? Fuerza el puerto: `./scripts/flash_bombercat.sh -f NFCGate -p /dev/ttyACM0`.

Comandos útiles del script:

```sh
./scripts/flash_bombercat.sh -l          # lista los firmwares disponibles
./scripts/flash_bombercat.sh -c -f NFCGate   # solo compila (no sube)
./scripts/flash_bombercat.sh -h          # ayuda completa
```

> **Camino A (dos placas):** repite el paso 0.2 con cada BomberCat, una a la vez.
> Si conectas ambas al mismo tiempo, pasa el puerto explícito con `-p` para no
> flashear la equivocada.

> El control corre a **115200 baud** y un solo programa puede tener el puerto
> abierto. **Cierra el Serial Monitor del IDE** (y el `-m` del script) mientras
> uses el CLI, o dará "port busy".

### 0.3 — Comprobar que firmware y CLI se hablan

Con tu venv de Python activado:

```sh
cd tools
pip install -r requirements.txt        # trae pyserial (solo la primera vez)
python3 bombercat.py device list       # debe aparecer tu puerto con ✓
python3 bombercat.py device info       # -> fw 0.7.0, role reader, state idle
```

Si ves `fw 0.7.0` y `state idle`, el plano de control funciona. (Puedes usar el
atajo `bombercat …` en vez de `python3 bombercat.py …` si lo tienes instalado.)

---

## Parte 1 — Requisitos comunes a ambos caminos

Da igual el camino que elijas: siempre necesitas **un servidor NFCGate** y que
ambos extremos compartan **servidor + sesión**.

### 1.1 — Levantar el servidor NFCGate

En una máquina de tu red (puede ser tu propia PC):

```sh
cd tools
python3 bombercat.py testserver run    # nfcgate-server local en :5566 (Docker)
```

El servidor escucha en el puerto **5566** de **esa** máquina. La IP que configures
luego con `--server` **debe ser la IP real de la máquina donde corriste
`testserver run`** — no `localhost`, no `127.0.0.1`: la placa se conecta por WiFi
y necesita una IP alcanzable en la LAN.

Averigua esa IP en la misma máquina donde levantaste el servidor:

```sh
hostname -I            # Linux -> p. ej. "192.168.1.5 172.17.0.1"
```

`hostname -I` puede imprimir **varias** direcciones. Quédate con la de tu red
local (la del mismo rango que tu router, típicamente `192.168.x.x` o `10.x.x.x`);
ignora las de interfaces virtuales como `172.17.x.x` (Docker) o `127.0.0.1`.

Con esa IP construyes el valor de `--server` — y **el mismo valor** va en la app
Android del Camino B:

```sh
--server 192.168.1.5:5566      # <IP de hostname -I>:5566
```

> Si la máquina cambia de red (o el router le da otra IP por DHCP), **vuelve a
> correr `hostname -I`** y reconfigura las placas con `config nfcgate --server …`:
> una IP vieja es la causa más común de que `run` no conecte.

### 1.2 — Reglas de oro del emparejamiento

- **WiFi 2.4 GHz obligatorio** — el módulo NINA-W102 de la BomberCat **solo opera
  en 2.4 GHz**; no soporta 5 GHz (ni 6 GHz). Si tu router publica una única red
  con "band steering" (2.4 y 5 GHz bajo el mismo SSID), separa las bandas en el
  router o crea un SSID exclusivo de 2.4 GHz para las placas. Un SSID de 5 GHz
  simplemente **no aparecerá** para la placa y `run` fallará con timeout de WiFi.
- **`--server` = IP de `hostname -I`** en la máquina del `testserver run` (Paso
  1.1), nunca `localhost`/`127.0.0.1`.
- **Mismo `--server`** (host:puerto) en los dos extremos.
- **Mismo `--session`** (1..255) en los dos extremos — si difiere, nunca hará `peer=yes`.
- **Roles opuestos**: un extremo `reader`, el otro `card`.

---

## Camino A — Relay con DOS BomberCat

Dos placas ya flasheadas (Parte 0) y el servidor arriba (Parte 1). Una placa hará
de **reader** (con una tarjeta física en su campo NFC) y la otra de **card**
(frente a un terminal/PoS).

Haz cada bloque de config **en la placa correspondiente** (conecta una a la vez, o
usa `--port` para dirigirte a cada una).

### A.1 — Configurar la placa READER

```sh
cd tools
python3 bombercat.py config wifi    --ssid "TuWiFi" --pass "TuClave"
python3 bombercat.py config nfcgate --server 192.168.1.5:5566 --session 42 --role reader
python3 bombercat.py config show    # verifica que quedó guardado en flash
```

### A.2 — Configurar la placa CARD

Mismo servidor y **misma sesión (42)**, rol opuesto:

```sh
python3 bombercat.py config wifi    --ssid "TuWiFi" --pass "TuClave"
python3 bombercat.py config nfcgate --server 192.168.1.5:5566 --session 42 --role card
python3 bombercat.py config show
```

### A.3 — Arrancar ambos extremos

En **cada** placa:

```sh
python3 bombercat.py run        # asocia WiFi, conecta al server, hace OP_SYN
python3 bombercat.py status     # busca: state=relaying, link connected=yes, peer=yes
```

Cuando `status` muestre **`peer=yes` en ambas**, los dos extremos se emparejaron.

### A.4 — Pasar tarjeta y observar el relay

1. Presenta la **tarjeta física** al campo NFC de la placa **reader**.
2. Acerca la placa **card** al **terminal/PoS**.
3. Observa el cruce de APDUs en vivo:

```sh
python3 bombercat.py monitor    # cmd:/resp: al pasar tarjeta ↔ terminal
```

El contador `relayed` de `status` debe subir y `monitor` mostrará los APDUs
cruzando entre los dos extremos.

---

## Camino B — Relay con UNA BomberCat + la app NFCGate (Android)

Aquí tu **única** BomberCat es un extremo del relay y la **app NFCGate** en un
móvil Android es el otro. Es la prueba de compatibilidad "fuerte": valida que
nuestro firmware habla el mismo protocolo que el cliente oficial de NFCGate.

Requisitos extra: un teléfono **Android con la app NFCGate** instalada y con NFC,
en la **misma red** que el servidor.

### Dos variantes según quién emula

| Variante | BomberCat | Móvil | Requiere root en el móvil |
|---|---|---|---|
| **B2** | `card` (emula frente al terminal) | **lector** de la tarjeta física | **No** — el modo lector no usa HCE |
| **B1** | `reader` (lee la tarjeta física) | **emulador** frente al terminal | **Sí** — ver B.0 |

> **¿Por qué B1 necesita root?** La HCE de Android solo entrega los APDU a una app
> que haya **registrado el AID** que pide el terminal, y la app NFCGate solo
> registra un AID de prueba (`F0010203040506`), **no** el PPSE ni AIDs de pago. Por
> eso en un móvil **stock** el `SELECT PPSE` del terminal nunca llega a NFCGate y no
> fluye nada (empareja pero cero APDU). Para emular AIDs arbitrarios la app usa su
> camino nativo (`DaemonManager`), que exige **root + Xposed + hook `nfcd`
> parcheado**..

### B.0 — Preparar el móvil rooteado (SOLO variante B1)

Salta este paso si haces B2. Para B1:

1. Root en el teléfono (p. ej. Magisk).
2. Instala un framework **Xposed**: **LSPosed** (con Zygisk o Riru).
3. En LSPosed, **activa el módulo NFCGate** (`nfcd`) y dale *scope* al **servicio NFC
   del sistema** (`com.android.nfc`) además de la app. **Reinicia** el teléfono.
4. Abre NFCGate → **Status** y confirma **`Native Hook Enabled`** y que el chipset
   es NCI (NXP/Broadcom/ST). Si el hook no queda activo, B1 no funcionará.

> **Probado OK (2026-08-19):** Motorola Edge 20 Pro rooteado, con `Native Hook
> Enabled`, emulando frente al terminal mientras la BomberCat `reader` leía una
> tarjeta EMV real. La transacción cruzó completa. El firmware `reader` emite una
> trama **INITIAL** con la config de la tarjeta (UID/SAK/ATQA/ATS) para que el móvil
> configure su HCE nativa y presente el tag.

### B.1 — Configurar la BomberCat

Elige el rol de la placa según qué quieras que capture. Ejemplo con la placa como
**reader** (captura la tarjeta física) y el móvil como el extremo emulador:

```sh
cd tools
python3 bombercat.py config wifi    --ssid "TuWiFi" --pass "TuClave"
python3 bombercat.py config nfcgate --server 192.168.1.5:5566 --session 42 --role reader
python3 bombercat.py config show
```

> Si prefieres que el **móvil** capture la tarjeta y la **placa** emule frente al
> terminal, pon `--role card` aquí y elige el rol opuesto en la app.

### B.2 — Configurar la app NFCGate

En la app Android:

1. Ajustes → **servidor**: la **misma IP y puerto** del Paso 1.1 (`192.168.1.5:5566`).
2. **Sesión**: el **mismo número** que la placa (`42`).
3. Modo/rol: el **opuesto** al de la placa. Si la placa es `reader`, el móvil hace
   de extremo de **emulación/relay** (el que presenta al terminal); si la placa es
   `card`, el móvil hace de **captura de tarjeta**.

### B.3 — Arrancar la BomberCat y unir el móvil a la sesión

En la placa:

```sh
python3 bombercat.py run
python3 bombercat.py status     # espera: link connected=yes
```

Luego, en la app, **inicia la sesión** con ese mismo número. Cuando ambos extremos
estén en la sesión, la placa reportará **`peer=yes`**:

```sh
python3 bombercat.py status     # peer=yes cuando el móvil se unió
python3 bombercat.py monitor    # stream en vivo de APDUs
```

### B.4 — Pasar tarjeta y observar

- Presenta la tarjeta física al extremo **reader** (la placa o el móvil, según lo configurado).
- Acerca el extremo **card/emulador** al terminal/PoS.
- En `monitor` verás los APDUs cruzando (`cmd:` / `resp:`) y `relayed` subiendo.

> **En B1 (placa `reader`)**, con la tarjeta ya sobre la placa, el monitor debe
> pasar de `reader: ...enviando trama INITIAL (coloca la tarjeta...)` a
> **`reader: trama INITIAL (config de tag) enviada al peer`**. Esa línea es la señal
> de que el móvil recibió la config y empezará a presentar el tag al terminal. Si se
> queda en `enviando trama INITIAL`, no hay tarjeta acoplada al `reader`.

---

## Qué observar / posibles tropiezos

| Síntoma | Causa habitual |
|---|---|
| El script no detecta la placa al flashear | Ponla en modo bootloader (doble reset → unidad `RPI-RP2`) o pasa `-p /dev/ttyACM0`. |
| `run` falla con timeout de WiFi | La red es de **5 GHz**: el NINA solo hace 2.4 GHz. Usa un SSID de 2.4 GHz. También revisa SSID/clave con `config show`. |
| `run` conecta al WiFi pero no al servidor | `--server` apunta a una IP equivocada. Corre `hostname -I` en la máquina del `testserver run` y reconfigura con esa IP:5566 (nunca `localhost`). |
| `run` falla | WiFi (SSID/clave, red 2.4 GHz) o `--server` inalcanzable. Revisa `config show`; `monitor` muestra el motivo (timeout WiFi, connect failed). |
| `peer=no` persistente | Los dos extremos no comparten `--session` o no apuntan al mismo servidor. En el Camino B, revisa que la app use la misma IP:puerto y sesión. |
| **B1: `peer=yes` pero cero APDU** (empareja y no fluye nada) | El móvil no está emulando el AID de pago. En **stock es imposible** (usa B2). Con móvil rooteado, revisa B.0: `Native Hook Enabled` en la página Status, módulo NFCGate activo en LSPosed con scope al servicio NFC, y reinicio tras activarlo. |
| **B1: monitor atascado en `enviando trama INITIAL`** | No hay tarjeta física acoplada al `reader`, o mal posicionada. Colócala y mantenla sobre la placa. |
| "port busy" / no abre | El Serial Monitor del IDE (o el `-m` del script) tiene el puerto. Ciérralo. |
| No detecta la placa (CLI) | Pasa el puerto explícito: `--port /dev/ttyACM0`. En Linux, tu usuario debe estar en el grupo `dialout` (ver Paso 0.1). |

**Autostart:** con SSID configurado en flash, la placa arranca el relay sola al
bootear (`RELAY_AUTOSTART=1`). Si quieres que espere al CLI, haz `bombercat stop`
o pon `RELAY_AUTOSTART 0` en `arduino_secrets.h` antes de flashear.

---

## Referencia rápida

**Flasheo (`scripts/flash_bombercat.sh`):**

```sh
./scripts/flash_bombercat.sh --setup            # preparar toolchain (1ª vez)
./scripts/flash_bombercat.sh -l                 # listar firmwares
./scripts/flash_bombercat.sh -f NFCGate [-m]    # flashear NFCGate (+monitor)
./scripts/flash_bombercat.sh -f NFCGate -p /dev/ttyACM0   # forzar puerto
```

**CLI de control (`tools/bombercat.py`):**

```sh
bombercat device list | info                 # descubrir / inspeccionar
bombercat config wifi    --ssid --pass       # credenciales WiFi
bombercat config nfcgate --server host[:port] --session N --role reader|card
bombercat config show                        # config actual
bombercat testserver run                     # nfcgate-server local (Docker)
bombercat run | stop | status | monitor      # arrancar / parar / estado / stream
```

Todos aceptan `--port/-p` (autodetección por handshake si se omite) y
`--save/--no-save` en los `config` (por defecto persiste en flash).

Ver también: [`tools/README.md`](../tools/README.md),
[`firmware/NFCGate/README.md`](../firmware/NFCGate/README.md),
[`NFCGATE_PLAN.md`](NFCGATE_PLAN.md).

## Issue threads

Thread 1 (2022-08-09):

MicroPython support?

andypiper, 2022-08-09:
The store page mentions that the board will support MicroPython, do you have a firmware and examples for this already that we could look at?

jazhe, 2022-08-09:
Hello @andypiper

Currently, we are working on adding more examples!
Keep up with our updates here, we will publish them later on. 😊

Hope you have a nice day!
Electronic Cats Support Team

andypiper, 2022-08-23:
Great, I may order one if there is a MicroPython board definition and source available.

Closed 2022-08-11.

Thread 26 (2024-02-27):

Compilation Issue with LittleFS_esp32 in Bombercat Project: 'LittleFS.h' file not found - WifiWebServer.ino

roozea, 2024-02-27:
Hello,

I'm currently working on the Bombercat project and encountered a compilation issue related to the **LittleFS_esp32 library by lorol**. My aim was to integrate **WifiWebServer.ino** functionality into the project, but despite correctly installing the LittleFS_esp32 library, the compiler is unable to locate the 'LittleFS.h' file.

**Environment:**
- Operating System: macOS Sonoma 14
- Arduino IDE: Arduino IDE 2.3.2
- LittleFS_esp32 Library Version: 1.0.6

**Error Message:**
In file included from /Users/[username]/Documents/Arduino/libraries/Preferences/src/Preferences.cpp:64:0:
/Users/[username]/Documents/Arduino/libraries/Preferences/src/prefs_impl_arduino.h:2:12: fatal error: LittleFS.h: No such file or directory
#include "LittleFS.h"
^~~~~~~~~~~~

**Steps to Reproduce:**
1. Installed the LittleFS_esp32 library via the Arduino IDE's Library Manager aiming to use it for the Bombercat project.
2. Tried to compile the Bombercat project which includes integration of the WifiWebServer, with the line `#include <LittleFS.h>` in the sketch.

**Troubleshooting Attempts:**
- Verified that the LittleFS_esp32 library is installed correctly in the Arduino libraries directory.
- Restarted the Arduino IDE after installing the library.

Despite these efforts, the issue persists, preventing successful compilation. I'm looking for insights or any additional steps I might be missing to ensure that the LittleFS_esp32 library is correctly recognized during the compilation process, especially in the context of integrating WifiWebServer into the Bombercat project.

Thank you in advance for your support and guidance.

Best regards,
Roozea

xpeqex, 2024-02-27:
Hi @roozea

Thank you for bringing this to our attention.

This error you are facing may be due to the Preference library you are using. While in the sketch there is a link and the instructions indicates the version should be 2.1.0, you must go to [ElectronicCats/Preferences ](https://github.com/ElectronicCats/Preferences) and download the library by creating a copy of the repo and not downloading the library from the releases section.

In any case, here is the direct link to download the library: [Preferences.zip](https://github.com/ElectronicCats/Preferences/archive/refs/heads/main.zip). Please download the library, replace the current files and try again.

Lastly, be assured we will modify the instructions for clearer understanding.
Let me know if this solves the problem.
😼

roozea, 2024-03-01:
Hello,

I wanted to extend my gratitude for your prompt and helpful response. Following your instructions, I downloaded the correct version of the Preferences library from ElectronicCats/Preferences, replaced the existing files, and I can confirm that this has resolved the compilation issue I was facing.

I greatly appreciate your willingness to modify the instructions to make them clearer, which will surely help to avoid similar confusion in the future.

Thank you again for your support and the provided solution.

Best regards,
@roozea

xpeqex, 2024-03-01:
Hey @roozea

I am glad to read this was the issue!

Please be assure we will modify this in the instructions and the wiki to make it clearer.

Feel free to reach out to us again.

<p align=right>
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
</p>

Closed 2024-03-01.

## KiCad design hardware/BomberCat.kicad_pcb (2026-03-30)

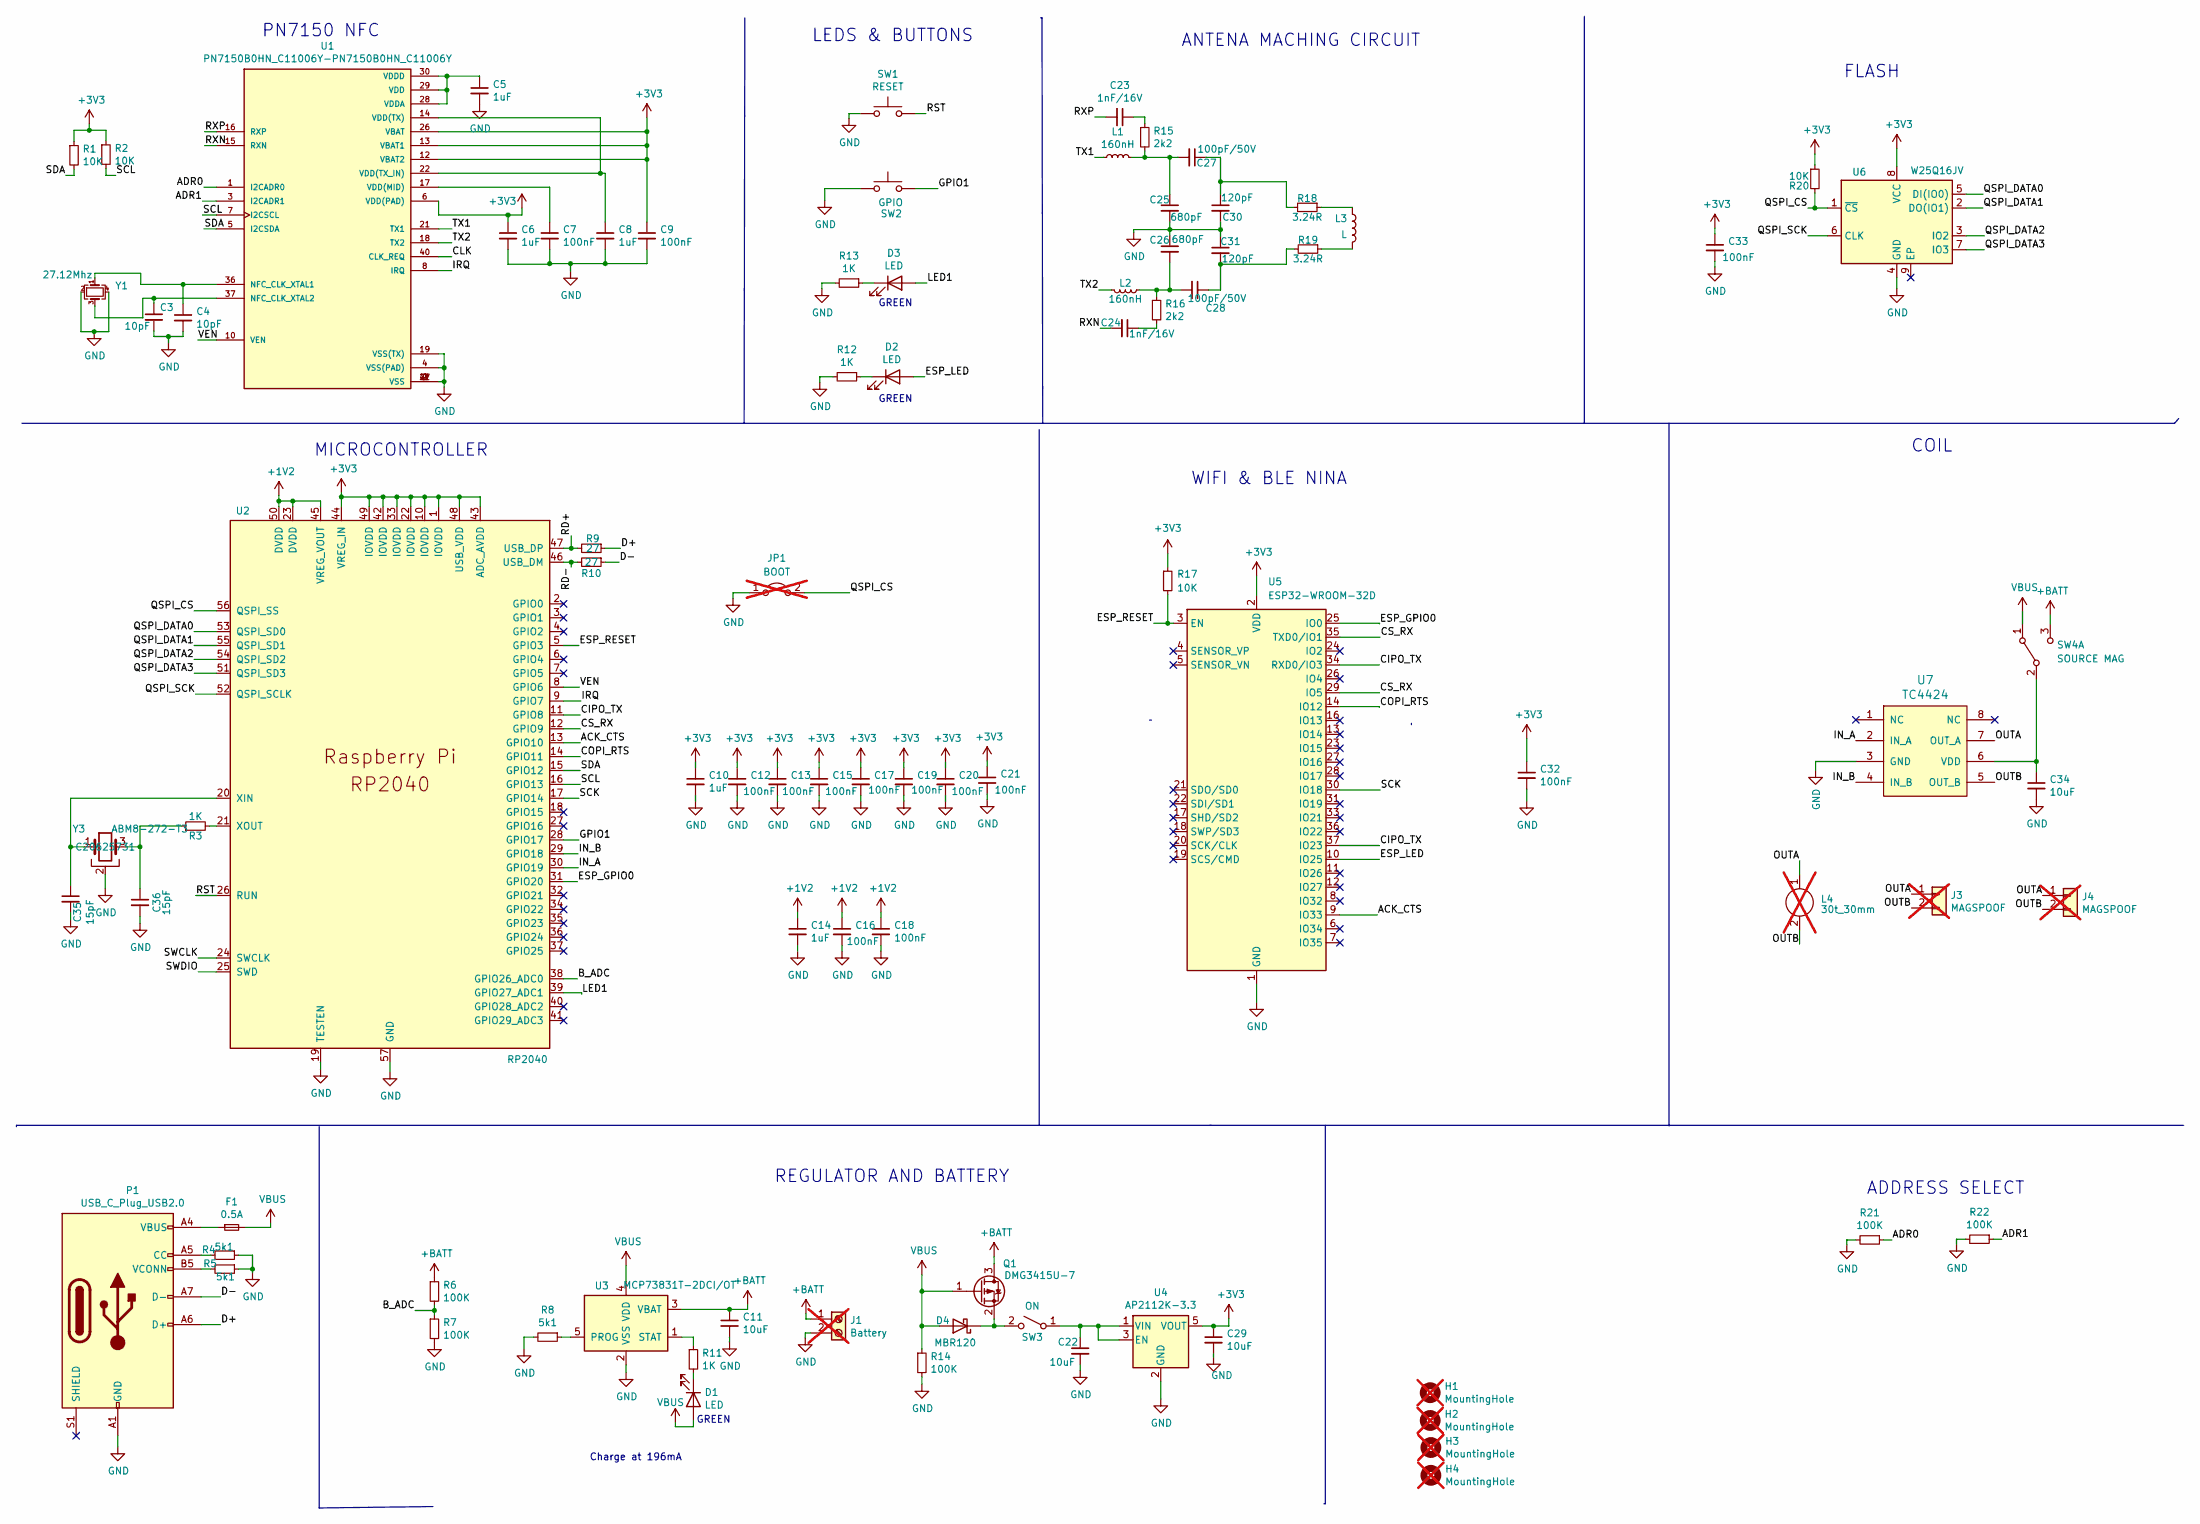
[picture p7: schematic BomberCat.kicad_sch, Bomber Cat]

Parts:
C3, C4: 10pF; C_0603_1608Metric; LCSC# C106245
C5, C6, C8: 1uF; C_0603_1608Metric; LCSC# C5673
C7, C9, C12, C13, C15, C16, C17, C18, C19, C20, C21, C32, C33: 100nF; C_0603_1608Metric; LCSC# C282519
C10, C14: 1uF; C_0603_1608Metric; LCSC# C15849
C11, C22: 10uF; C_0603_1608Metric; LCSC# C85713
C23, C24: 1nF/16V; C_0603_1608Metric; LCSC# C519403
C25, C26: 680pF; C_0603_1608Metric; LCSC# C107055
C27, C28: 100pF/50V; C_0603_1608Metric; LCSC# C14665
C29, C34: 10uF; C_0603_1608Metric; LCSC# C96446
C30, C31: 120pF; C_0603_1608Metric; LCSC# C107035
C35, C36: 15pF; C_0603_1608Metric; LCSC# C107037
D1, D2, D3: LED; LED_0805_2012Metric_Pad1.15x1.40mm_HandSolder; LCSC# C965815
D4: MBR120; D_SOD-123F; LCSC# C130880
F1: 0.5A; Fuse_0805_2012Metric; LCSC# C2649565
H1, H2, H3, H4: MountingHole; MountingHole_2.2mm_M2; not fitted
J1: Battery; PinHeader_1x02_P2.54mm_Vertical; not fitted
J3, J4: MAGSPOOF; PinHeader_1x02_P2.54mm_Vertical; not fitted
JP1: BOOT; SolderJumper-2_P1.3mm_Open_TrianglePad1.0x1.5mm; not fitted
L1, L2: 160nH; L_0603_1608Metric_Pad1.05x0.95mm_HandSolder; LCSC# C434822
L3: L; MOLEX_1661; LCSC# C22418213
L4: 30t_30mm; Coil_30t_30mm_0.2_0.2_0.6_0.3; not fitted
P1: USB_C_Plug_USB2.0; C393939; LCSC# C393939
Q1: DMG3415U-7; SOT-23; LCSC# C96616
R1, R2, R17, R20: 10K; R_0603_1608Metric; LCSC# C2930027
R3, R11, R12, R13: 1K; R_0603_1608Metric; LCSC# C112433
R4, R5, R8: 5k1; R_0603_1608Metric; LCSC# C23186
R6, R7, R14, R21, R22: 100K; R_0603_1608Metric; LCSC# C15458
R9, R10: 27; R_0603_1608Metric; LCSC# C403464
R15, R16: 2k2; R_0603_1608Metric; LCSC# C113303
R18, R19: 3.24R; R_0603_1608Metric; LCSC# C166817
SW1: RESET; SW_SPST_TL3342; LCSC# C318884
SW2: GPIO; SW_SPST_TL3342; LCSC# C318884
SW3: ON; JS102011SAQN; LCSC# C221660
SW4: SOURCE MAG; JS202011CQN; LCSC# C221663
U1: PN7150B0HN_C11006Y-PN7150B0HN_C11006Y; QFN-40-1EP_6x6mm_P0.5mm_EP4.6x4.6mm; LCSC# C702907
U2: RP2040; RP2040-QFN-56; LCSC# C2040
U3: MCP73831T-2DCI/OT; SOT-23-5; LCSC# C424093
U4: AP2112K-3.3; SOT-23-5; LCSC# C150742
U5: ESP32-WROOM-32D; ESP32-WROOM-32; LCSC# C473012
U6: W25Q16JV; SON50P200X300X40-9N; LCSC# C2843335
U7: TC4424; SOIC-8_3.9x4.9mm_P1.27mm; LCSC# C7498963
Y1: 27.12Mhz; Crystal_SMD_2016-4Pin_2.0x1.6mm; LCSC# C252276
Y3: ABM8-272-T3; Crystal_SMD_Abracon_ABM8G-4Pin_3.2x2.5mm; LCSC# C20625731

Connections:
+1V2: C14.1, C16.1, C18.1, U2.23 (DVDD), U2.45 (VREG_VOUT), U2.50 (DVDD)
+3V3: C6.1, C9.1, C10.1, C12.1, C13.1, C15.1, C17.1, C19.1, C20.1, C21.1, C29.1, C32.1, C33.1, R1.1, R2.1, R17.1, R20.1, U1.6 (VDD(PAD)), U1.12 (VBAT2), U1.13 (VBAT1), U1.26 (VBAT), U2.1 (IOVDD), U2.10 (IOVDD), U2.22 (IOVDD), U2.33 (IOVDD), U2.42 (IOVDD), U2.43 (ADC_AVDD), U2.44 (VREG_IN), U2.48 (USB_VDD), U2.49 (IOVDD), U4.5 (VOUT), U5.2 (VDD), U6.8 (VCC)
+BATT: C11.1, J1.1, Q1.3 (D), R6.1, SW4.3 (C), U3.3 (VBAT)
/ACK_CTS: U2.13 (GPIO10), U5.9 (IO33)
/ADR0: R21.1, U1.1 (I2CADR0)
/ADR1: R22.1, U1.3 (I2CADR1)
/B_ADC: R6.2, R7.1, U2.38 (GPIO26_ADC0)
/CIPO_TX: U2.11 (GPIO8), U5.34 (RXD0/IO3), U5.37 (IO23)
/CLK: U1.40 (CLK_REQ)
/COPI_RTS: U2.14 (GPIO11), U5.14 (IO12)
/CS_RX: U2.12 (GPIO9), U5.29 (IO5), U5.35 (TXD0/IO1)
/D+: P1.A6 (D+), R9.1
/D-: P1.A7 (D-), R10.1
/ESP_GPIO0: U2.31 (GPIO20), U5.25 (IO0)
/ESP_LED: D2.2 (A), U5.10 (IO25)
/ESP_RESET: R17.2, U2.5 (GPIO3), U5.3 (EN)
/GPIO1: SW2.2, U2.28 (GPIO17)
/IN_A: U2.30 (GPIO19), U7.2 (IN_A)
/IN_B: U2.29 (GPIO18), U7.4 (IN_B)
/IRQ: U1.8 (IRQ), U2.9 (GPIO7)
/LED1: D3.2 (A), U2.39 (GPIO27_ADC1)
/OUTA: J3.1, J4.1, L4.1, U7.7 (OUT_A)
/OUTB: J3.2, J4.2, L4.2, U7.5 (OUT_B)
/QSPI_CS: JP1.2 (B), R20.2, U2.56 (QSPI_SS), U6.1 (~CS)
/QSPI_DATA0: U2.53 (QSPI_SD0), U6.5 (DI(IO0))
/QSPI_DATA1: U2.55 (QSPI_SD1), U6.2 (DO(IO1))
/QSPI_DATA2: U2.54 (QSPI_SD2), U6.3 (IO2)
/QSPI_DATA3: U2.51 (QSPI_SD3), U6.7 (IO3)
/QSPI_SCK: U2.52 (QSPI_SCLK), U6.6 (CLK)
/RD+: R9.2, U2.47 (USB_DP)
/RD-: R10.2, U2.46 (USB_DM)
/RST: SW1.2, U2.26 (RUN)
/RXN: C24.2, U1.15 (RXN)
/RXP: C23.2, U1.16 (RXP)
/SCK: U2.17 (GPIO14), U5.30 (IO18)
/SCL: R2.2, U1.7 (I2CSCL), U2.16 (GPIO13)
/SDA: R1.2, U1.5 (I2CSDA), U2.15 (GPIO12)
/SWCLK: U2.24 (SWCLK)
/SWDIO: U2.25 (SWD)
/TX1: L1.1, U1.21 (TX1)
/TX2: L2.2, U1.18 (TX2)
/VEN: U1.10 (VEN), U2.8 (GPIO6)
GND: C3.2, C4.2, C5.2, C6.2, C7.2, C8.2, C9.2, C10.2, C11.2, C12.2, C13.2, C14.2, C15.2, C16.2, C17.2, C18.2, C19.2, C20.2, C21.2, C22.2, C25.2, C26.1, C29.2, C30.2, C31.1, C32.2, C33.2, C34.2, C35.2, C36.2, J1.2, JP1.1 (A), P1.A1 (GND), P1.A12 (GND), P1.B1 (GND), P1.B12 (GND), R4.1, R5.1, R7.2, R8.2, R12.2, R13.2, R14.2, R21.2, R22.2, SW1.1, SW2.1, U1.2 (VSS), U1.4 (VSS(PAD)), U1.9 (VSS), U1.19 (VSS(TX)), U1.27 (VSS), U1.41 (VSS), U2.19 (TESTEN), U2.57 (GND), U3.2 (VSS), U4.2 (GND), U5.1 (GND), U5.15 (GND), U5.38 (GND), U5.39 (GND), U6.4 (GND), U7.3 (GND), Y1.2, Y1.4, Y3.2
unnamed: C23.1, R15.1
unnamed: C24.1, R16.2
unnamed: C25.1, C27.2, L1.2, R15.2
unnamed: C26.2, C28.2, L2.1, R16.1
unnamed: C27.1, C30.1, R18.2
unnamed: C28.1, C31.2, R19.2
unnamed: C36.1, R3.1, Y3.3
unnamed: D1.1 (K), R11.2
unnamed: D2.1 (K), R12.1
unnamed: D3.1 (K), R13.1
unnamed: D4.1 (K), Q1.2 (S), SW3.2 (B)
unnamed: F1.1, P1.A4 (VBUS), P1.A9 (VBUS), P1.B4 (VBUS), P1.B9 (VBUS)
unnamed: L3.1, R18.1
unnamed: L3.2, R19.1
unnamed: P1.A5 (CC), R4.2
unnamed: P1.B5 (VCONN), R5.2
unnamed: C22.1, SW3.1 (A), U4.1 (VIN), U4.3 (EN)
unnamed: C34.1, SW4.2 (B), U7.6 (VDD)
unnamed: C4.1, U1.36 (NFC_CLK_XTAL1), Y1.1
unnamed: C3.1, U1.37 (NFC_CLK_XTAL2), Y1.3
unnamed: C7.1, U1.17 (VDD(MID))
unnamed: C8.1, U1.14 (VDD(TX)), U1.22 (VDD(TX_IN))
unnamed: C5.1, U1.28 (VDDA), U1.29 (VDD), U1.30 (VDDD)
unnamed: C35.1, U2.20 (XIN), Y3.1
unnamed: R3.2, U2.21 (XOUT)
unnamed: R8.1, U3.5 (PROG)
unnamed: R11.1, U3.1 (STAT)
VBUS: D1.2 (A), D4.2 (A), F1.2, Q1.1 (G), R14.1, SW4.1 (A), U3.4 (VDD)

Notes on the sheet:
GREEN
COIL
Charge at 196mA
ANTENA MACHING CIRCUIT
PN7150 NFC
LEDS & BUTTONS
WIFI & BLE NINA
MICROCONTROLLER
REGULATOR AND BATTERY
FLASH
ADDRESS SELECT

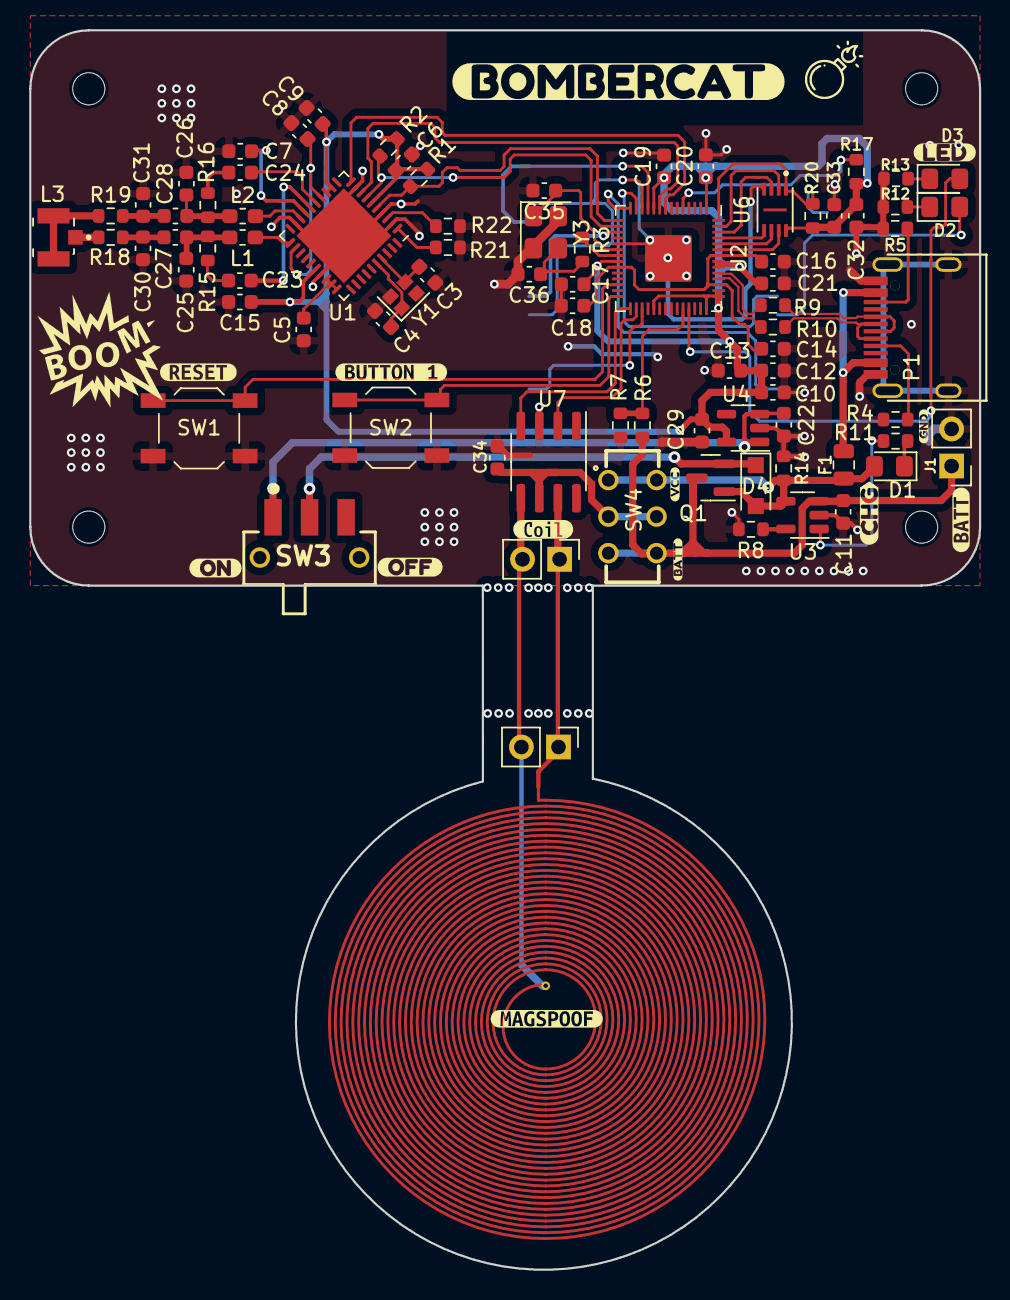
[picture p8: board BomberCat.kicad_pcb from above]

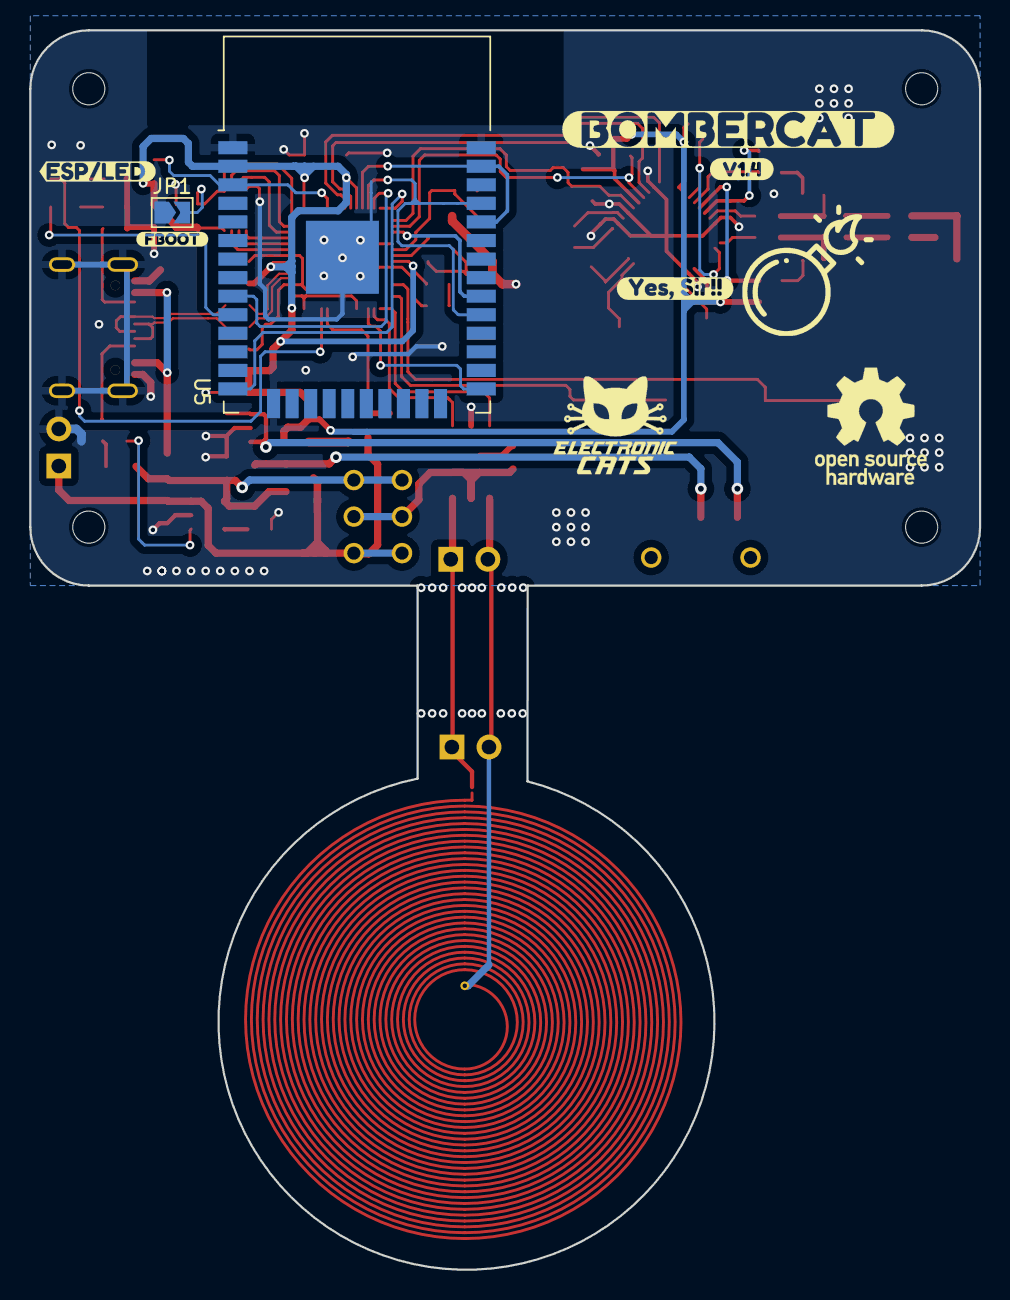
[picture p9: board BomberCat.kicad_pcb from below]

Board: 2 copper layers, 65.0 x 84.8 mm, 106 parts (7 on the bottom side), 68 nets.

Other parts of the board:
kibuzzard-62CC5B78, kibuzzard-62CC5B78#2: G***; kibuzzard-62CC5B78
kibuzzard-62CC5BEF: G***; kibuzzard-62CC5BEF
kibuzzard-62CC9A49: G***; kibuzzard-62CC9A49
kibuzzard-62CC595D: G***; kibuzzard-62CC595D
kibuzzard-62CC5892: G***; kibuzzard-62CC5892
kibuzzard-62E1B288: G***; kibuzzard-62E1B288
kibuzzard-62E1B296: G***; kibuzzard-62E1B296
kibuzzard-62E41048: G***; kibuzzard-62E41048
kibuzzard-67E317B3: G***; kibuzzard-67E317B3
kibuzzard-67F6D9A7: G***; kibuzzard-67F6D9A7
kibuzzard-67F6D96D: G***; kibuzzard-67F6D96D
kibuzzard-67F6D992: G***; kibuzzard-67F6D992
kibuzzard-67F6E5D9: G***; kibuzzard-67F6E5D9
kibuzzard-67F6E601: G***; kibuzzard-67F6E601
kibuzzard-67FD52FB: G***; kibuzzard-67FD52FB
kibuzzard-67FEA7C0: G***; kibuzzard-67FEA7C0
kibuzzard-698D0712: G***; kibuzzard-698D0712

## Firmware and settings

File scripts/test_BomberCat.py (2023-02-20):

"""
//-----------------------------------
//  Command test script for BomberCat Client/Host
//  by Andres Sabas, Electronic Cats (https://electroniccats.com/)
//  by Raul Vargas
//  Date: 24/11/2022
//
//  This script sends serial commands from a list to the BomberCat client.
//
//  Development environment specifics:
//  IDE: gedit
//  Hardware Platform:
//  Ubuntu Linux - Intel
//
//  Thanks Wallee for support this project open source https://en.wallee.com/
//
//  Electronic Cats invests time and resources providing this open source code,
//  please support Electronic Cats and open-source hardware by purchasing
//  products from Electronic Cats!
//
//  This code is beerware; if you see me (or any other Electronic Cats
//  member) at the local, and you've found our code helpful,
//  please buy us a round!
//  Distributed as-is; no warranty is given.
"""

import serial
import time
import sys

ser = serial.Serial()
ser.port = '/dev/ttyACM0'
ser.baudrate = 9600
ser.bytesize = serial.EIGHTBITS
ser.parity = serial.PARITY_NONE
ser.stopbits = serial.STOPBITS_ONE
ser.timeout = 1

cmds = ["mode_ms", "set_h-", "get_config", "mode_ms", \
	"set_h-", "mode_ms"] # put here the commands to be processed
	
print(sys.argv[1])	
	
N = 5 # commands number minus 1 in cmds

time.sleep(1)
ser.open()

e = 0 # index in cmds

while True:
	if ser.is_open:
		cmd = cmds[e] #get the command in turn
		if cmd[3:5] == '_h': # check for select host
			cmd = cmd + sys.argv[1]
			print(cmd)
		#if cmd[4:6] == '_h':
		#	cmd = cmd + sys.argv[1]
			
		cmd = cmd + '\r\n'	
			

	if ser.in_waiting == 0:
		for i in cmd:
			ser.write(i.encode())
			time.sleep(0.001)

	while(ser.in_waiting == 0):
		pass
		
	time.sleep(0.01)
		
	if ser.in_waiting > 0:
		msg = ser.read(ser.in_waiting)
		cad = msg.decode()
		
		if cad[:2] == 'ER':
			print('ERROR:', end = " ")
			print(cmds[e], end = " ")
			print('command could not be executed')
		
		elif cad[:2] == 'OK':
			print("OK")
					
		else:
			print (cad)	
		

	e = e + 1
	if e > N:
		e = 0
            
	ser.flush()
	time.sleep(5)

ser.close()

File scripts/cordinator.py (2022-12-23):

"""
//-----------------------------------
//  Cordinator script for BomberCat Client/Host
//  by Andres Sabas, Electronic Cats (https://electroniccats.com/)
//  by Raul Vargas
//  Date: 22/11/2022
//
//  This script receives requests from BomberCat clients that want 
//  to connect to a given BomberCat host, it also takes care of releasing 
//  the status of the host once the connection is terminated.
//
//  Development environment specifics:
//  IDE: gedit
//  Hardware Platform:
//  Ubuntu Linux - Intel
//
//  Thanks Wallee for support this project open source https://en.wallee.com/
//
//  Electronic Cats invests time and resources providing this open source code,
//  please support Electronic Cats and open-source hardware by purchasing
//  products from Electronic Cats!
//
//  This code is beerware; if you see me (or any other Electronic Cats
//  member) at the local, and you've found our code helpful,
//  please buy us a round!
//  Distributed as-is; no warranty is given.
"""

import paho.mqtt.client as mqtt #import the client1
import time
import sys

# Initializing a queue
queue = []
shosts = ['#'] * 84 # 42 hosts max

########################################

def on_message(client, userdata, message):
    command = str(message.payload.decode("utf-8"))
    print(str(message.payload.decode("utf-8")))
    
    #print(command[0])
    if command[0] == 'c' or command[0] == 'h' or command[0] == 'u':
        # Adding elements to the queue
        queue.append(command)
    
    # a request has been received, it is queued

########################################

broker_address = "test.mosquitto.org"
if(len(sys.argv) > 1):
    broker_address = sys.argv[1]

print("Creating new instance.")
client = mqtt.Client("CORDINATOR") #create new instance
client.on_message = on_message #attach function to callback
print("connecting to broker ")
print(broker_address)

client.connect(broker_address) #connect to broker

client.loop_start() #start the loop
print("Subscribing to topic","queue")
client.subscribe("queue")

s = "".join(shosts)
print(s)
client.publish("hosts",s)

while True:

    time.sleep(0.5) # wait

    # host requests are processed
    while True:
        if queue:
            result = queue.pop(0)
            print(result)
            
            if result[0] == 'u':
                s = "".join(shosts)    
                print(s)    
                client.publish("hosts",s)                
                continue    
                    
            if result[0] == 'c':
                # new client
                if result[4] == '#' and result[5] == '#':
                    print("New client added")
                    s = "".join(shosts)
                    print(s)            
                    client.publish("hosts",s)
                    continue

                # check if the host is busy
                # check if there is another client instance
                
                for i in range(0,len(shosts),2):
                    #print(shosts[i])
                    #print(shosts[i+1])
                    if shosts[i] == result[1] and shosts[i+1] == result[2]:
                        shosts[i] = '#'
                        shosts[i+1] = '#'
                               
                if ((ord(result[5]) - 48) + (ord(result[4]) - 48)*10) > 41:
                    continue  
                
                if shosts[2*((ord(result[4]) - 48)*10 + ord(result[5]) - 48) + 1] == '#':
                    print("Host vacant")
           
                    # status is updated and required messages are published
                    
                    shosts[2*((ord(result[4]) - 48)*10 + ord(result[5]) - 48) + 1] = result[2]
                    shosts[2*((ord(result[4]) - 48)*10 + ord(result[5]) - 48)] = result[1]
                    s = "".join(shosts)
                    print(s)
            
                    #shosts[ord(result[3]) - 48] = result[1]
                    client.publish("hosts",s)
                
                else:
                    print("Busy host")
                    s = 'h' + result[4] + result[5] + '-'
                    client.publish("status",s)
                    
                      
            elif result[0] == 'h': # release the host        
                # status is updated and required messages are published
            
                shosts[2*((ord(result[1]) - 48)*10 + ord(result[2]) - 48) + 1] = '#'
                shosts[2*((ord(result[1]) - 48)*10 + ord(result[2]) - 48)] = '#'
                s = "".join(shosts)
                print(s)
            
                client.publish("hosts",s)
            
        else:
            break  
     
client.loop_stop() #stop the loop

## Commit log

2022-06-17 Init BomberCat
    [BomberCat.kicad_pcb, BomberCat.kicad_sch, BomberCat.sch]
2022-06-24 Replace ATSAMD21E18A with RP2040
    [BomberCat.kicad_sch]
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2022-06-27 Assigned footprints
    [BomberCat.kicad_sch]
2022-06-29 change boot jumper, add magspoof
    [BomberCat.kicad_sch]
2022-06-29 add not connect
    [BomberCat.kicad_sch]
2022-06-30 add footprint memory and fix path footprints
    [BomberCat.kicad_pcb, BomberCat.kicad_sch]
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2022-07-07 fix name device
2022-07-07 add switch source magspoof
    [BomberCat.kicad_sch]
2022-07-08 change pins NINA
    [BomberCat.kicad_sch]
2022-07-08 update schematic SDA and SCL
    [BomberCat.kicad_sch]
2022-07-09 update component groups
    [BomberCat.kicad_pcb, BomberCat.kicad_sch]
2022-07-09 Add grouped blocks for floorplan
    [BomberCat.kicad_pcb, BomberCat.kicad_sch]
2022-07-11 add layout waiting for switch's
    [BomberCat.kicad_pcb, BomberCat.kicad_sch]
2022-07-11 add labels
    [BomberCat.kicad_pcb]
2022-07-11 layout update 0 unconnected added switchs
    [BomberCat.kicad_pcb, BomberCat.kicad_sch, BomberCat.sch]
2022-07-11 add logos for defcon edition
    [BomberCat.kicad_pcb]
2022-07-11 fix jumper for boot mode add 3Ds
    [BomberCat.kicad_pcb, BomberCat.kicad_sch]
2022-07-11 fix traces
    [BomberCat.kicad_pcb]
2022-07-11 update BOM
    [BomberCat.kicad_sch]
2022-07-15 Check and update BOM
    [BomberCat.kicad_sch]
2022-07-16 add no connect
    [BomberCat.kicad_sch]
2022-07-27 Add labels on/off, source mag
    [BomberCat.kicad_pcb]
2022-07-29 add label battery
    [BomberCat.kicad_pcb]
2022-07-29 change resistor charger
    [BomberCat.kicad_sch]
2022-08-06 Add new labels
    [BomberCat.kicad_pcb]
2022-08-10 update fuse footprint
    [BomberCat.kicad_pcb, BomberCat.kicad_sch]
2022-08-10 update traces
    [BomberCat.kicad_pcb]
2022-08-10 v1.1 production
    [BomberCat.kicad_pcb]
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2022-09-23 example data cvs
    [data.csv]
2022-09-26 fix label R5 and R12
    [BomberCat.kicad_pcb]
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2022-11-15 added case stl files
    [Bottom_client.stl, Bottom_host.stl, Card_holder.stl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]
2022-11-25 Added new top logo
    [Bottom_client.stl, Bottom_host.stl, Card_holder.stl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]
2022-11-28 fix square bracket
2022-12-06 Changed resistor R8 to 5.1K and updated BOM
    [BomberCat.kicad_sch]
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2022-12-08 change flags and led error, remove ERROR prints
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2022-12-24 Update examples magspoof
    [data.csv]
2023-01-06 Update version schematic
    [BomberCat.kicad_sch]
2023-01-06 add BOM connector antenna
    [BomberCat.kicad_sch]
2023-01-11 WifiServerTest compilation OK
    The file compiles correctly, trying to convert the html file to String or another type so Arduino will be able to open it.
2023-02-09 print ERROR in client if card no detected
2023-02-16 fix set_delay, comments in test script
    [test_BomberCat.py]
2023-04-11 update to kicad7
    [BomberCat.kicad_pcb, BomberCat.kicad_sch]
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2023-04-13 Change serigraphy version to "v1.2"
    [BomberCat.kicad_pcb]
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2023-04-18 fix: set the width of the sign in button to 275px
2023-04-21 fix: change the color of the footer icon link according to the current page
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2023-05-03 update 12Mhz cristal part number
    [BomberCat.kicad_sch]
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2023-05-10 fix: run magspoof without blocking the main thread
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2023-06-07 docs: update readme - add libraries required - add platform required - remove arduino_secrets - add connection to wifi station
2023-06-08 fix: run detect tags without blocking the main thread
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2023-06-23 fix: set emulate button as default
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2023-08-02 fix: decode track 1
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2024-04-30 fix(docs): correct directory name
    [Bottom_client.stl, Bottom_host.stl, Card_holder.stl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]
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2025-03-07 feat(hw): update components labels
    [BomberCat.kicad_pcb]
2025-03-24 feat(hw): add Embedded Antenna
    [BomberCat.kicad_pcb, BomberCat.kicad_sch]
2025-03-25 feat(hw): update Antenna
    [BomberCat.kicad_pcb]
2025-03-25 fix(hw): update Thickness specifications
    [BomberCat.kicad_pcb]
2025-04-04 fix(hw): update part numbers
    [BomberCat.kicad_pcb, BomberCat.kicad_sch]
2025-04-07 fix (hw): Update part numbers
    [BomberCat.kicad_sch]
2025-04-07 fix(hw): Update Batt Label
    [BomberCat.kicad_pcb]
2025-04-08 fix(hw): Update LCSC part numbers in schematic
    Updates the LCSC part numbers in the schematic to ensure their availability
    [BomberCat.kicad_sch]
2025-04-09 fix(hw): update BOM
    [BomberCat.kicad_sch]
2025-04-09 fix(hw): update routes and labels
    [BomberCat.kicad_pcb]
2025-04-14 feat(hw): update routes and resize coil arm
    [BomberCat.kicad_pcb]
2025-04-15 fix(hw):update labels
    [BomberCat.kicad_pcb]
2025-04-15 feat(hw): update tracks, remove switch position change and resize coil arm,
    [BomberCat.kicad_pcb]
2025-04-15 fix(hw): update tracks width
    [BomberCat.kicad_pcb]
2025-04-15 fix(hw): update manf#s
    [BomberCat.kicad_sch]
2025-04-18 fix(hw): add alternative part number of battery charger
    [BomberCat.kicad_sch]
2025-05-07 fix(hw): update PN7150 module version
    [BomberCat.kicad_sch]
2025-06-12 feat(hw): update Y3 footprint
    [BomberCat.kicad_pcb, BomberCat.kicad_sch]
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2026-02-11 Feat: fix tag V1.4
    [BomberCat.kicad_pcb]
2026-08-12 feat: Introduce bombercat CLI tool framework
    Establishes the foundational structure for the new 'bombercat' multi-tool
    command-line utility. This includes:
    - Main entry point (`bombercat.py`) with vendor dependency handling
    - Modular package organization for `core` and `utils`
    - CLI definition using `click` for command parsing and help
    - Rich-based console output helpers and logging setup
    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
2026-08-12 feat: Add dev tooling subcommands and USB connection module
    Integrates `proto` and `testserver` CLI subcommands to streamline
    NFCGate-related development tasks such as protobuf regeneration
    and local nfcgate-server management.
    Also introduces `usb_connection.py` to lay the groundwork for
    future USB communication with bombercat devices.
2026-08-12 feat: Add vendored NFCGate protocol definitions and documentation
    Integrates the `c2c.proto` and `c2s.proto` messages, along with
    nanopb options for static memory allocation, from the NFCGate
    `protocol` repository.
    This introduces the necessary protobuf message structures for the
    firmware to communicate via the NFCGate relay protocol. The `UPSTREAM.md`
    file documents the specific pinned protocol version, wire format,
    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
2026-08-12 feat: Add tooling for NFCGate protobuf generation and relay server testing
    This introduces `gen_proto.sh` for reproducible generation of Nanopb C sources from vendored NFCGate protocol definitions, ensuring consistent firmware builds.
    It also adds a local `nfcgate-server` test fixture (`tools/testserver/`) to enable isolated development and testing of the NFCGate relay feature. This includes a Docker setup for the server, a client smoke test, and documentation, allowing developers to validate the wire protocol without physical hardware or the Android app.
2026-08-12 feat: Introduce BomberCatCore shared Arduino library
    This establishes a reusable foundation for the NFCGate relay firmware,
    centralizing functionalities previously scattered across sketches.
    It includes modules for NFC controller management (PN7150 wrapper),
    persistent configuration (WiFi, relay role), level-gated logging, and
    hex utilities. The library also integrates the Nanopb runtime and
    generated NFCGate protobuf definitions, providing core components for
    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
2026-08-12 feat: Introduce NFCGate wire protocol codec and TCP link transport
    Introduce `NfcGateCodec` for encoding/decoding NFCGate `NFCData` and
    `ServerData` messages, handling the length-prefixed framing. Also add
    `NfcGateLink`, which provides TCP transport over an Arduino `Client&`
    to the `nfcgate-server`.
    The codec is designed to be Arduino-free, enabling host-side testing of the
    wire format against a local `nfcgate-server` fixture. This separation
    allows for robust validation of the communication protocol without
    physical hardware.
    These components are essential for establishing a functional NFCGate
    relay, progressing the project into Fase 3 of the development plan.
    The `CoreSelfTest` example i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
2026-08-13 feat: Increase read timeout for relay startup and improve error messaging in CLI
2026-08-13 feat: Enhance USB handling and error messaging for BomberCat device discovery
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2026-08-17 fix: Force reconnect after persistent unanswered commands
    The RelayEngine can get stuck waiting indefinitely for responses to forwarded NFC commands when the underlying TCP link to the peer is half-open (e.g., server closed its side, but WiFiNINA's connected() and write() still report success). This causes commands to silently fail to reach the server, making the response impossible.
    This change introduces a counter for consecutive command timeouts. If the configured threshold is met, it signals a probable dead link and forces a State::Error to trigger a full TCP reconnect and re-synchronization.
2026-08-17 fix: Implement retry and re-arm for reader-side NFC commands
    The reader-side RelayEngine could drop the first command of a new transaction if the physical card's ISO-DEP session had become stale or if the initial transceive timed out. This left the card peer waiting indefinitely for a response.
    This change introduces a retry mechanism for `waitForTag` and `readerTransceive` attempts, coupled with a full `beginReaderMode()` re-arm of the NFC front-end. This allows the reader to self-heal and re-activate the card, preventing dropped commands and ensuring reliable relaying. The `AWAIT_TIMEOUT_MS` is also increased to accommodate these recovery attempts.
2026-08-17 fix: Correct NFC relay for EMV transactions and NFCGate app compatibility
    This commit addresses several critical issues to improve the robustness and correctness
    of the NFC relay, particularly for complex EMV transactions and compatibility with
    the NFCGate Android application:
    * **Reader Response Handling:** `readerTransceive` now correctly implements
    the PN7150's "double-receive" behavior, which delivers the actual APDU
    response on the second data packet, not the first intermediate frame.
    This prevents transactions from breaking at commands like GPO.
    * **Large Card Responses:** `cardSend` now fragments ISO-DEP responses
    larger than 255 bytes (e.g., EMV READ RECORDs) acr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
2026-08-18 fix: Prevent readerTransceive stalls and introduce runtime logging control
    This commit addresses a critical performance issue in `NfcController::readerTransceive` where a 2000ms busy-wait would occur if a card responded with only a single data packet. This excessive delay often caused NFC transactions to time out, particularly with EMV readers. The logic is now IRQ-gated, polling for a genuine second packet only for a short `SECOND_PACKET_WINDOW_MS` before concluding the card is single-packet and returning immediately.
    Additionally, a `loglevel` serial command is added to allow runtime adjustment of the firmware's logging verbosity. The relay now defaults to `LogLevel::Warn` to minimize `Se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
2026-08-18 fix: Update firmware version to 0.9.4 and eliminate significant NFC receive latency
    This commit introduces `receiveNoGarbage()`, a custom implementation replacing the library's `cardModeReceive()`. This addresses two critical performance bottlenecks:
    * **Removes ~23ms of uninitialized garbage I2C transmission** on every relayed receive, as the original `writeData(Ans, 255)` was useless and blocking (H2 / Fase C).
    * **Prevents ~2s busy-waits** in `readerTransceive` for single-packet cards. The original `cardModeReceive()` hardcoded a 2000ms internal timeout, causing EMV terminals to abandon transactions. The new logic ensures reads are IRQ-gated and do not impose unnecessary delays when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
2026-08-18 fix: Update firmware version to 0.9.5 and optimize TCP header read latency
    Refactors `NfcGateLink::poll()` to read the 4-byte TCP frame length header in a single bulk operation from the `WiFiClient`. This significantly reduces SPI transaction overhead when communicating with the WiFiNINA coprocessor.
    The previous byte-by-byte approach incurred up to 8 SPI round-trips (4 `read()` + 4 `available()`) per header. With this change, a single bulk read reduces this to two (one `available()` and one `read()`) when the header is fully buffered, improving data link efficiency and reducing latency (Fase F, H5).
2026-08-18 fix: enhance transaction boundary handling in RelayEngine
2026-08-19 fix: enable NFCGate emulator compatibility via initial tag config
    Sends a one-off INITIAL frame containing the physical card's NFC-A and ISO-DEP
    activation parameters (UID, ATQA, SAK, ATS) to the peer.
    This allows a rooted NFCGate emulator peer (Camino B1) to correctly configure
    its Host Card Emulation (HCE) and present the physical card to its terminal
    before the terminal issues the initial SELECT PPSE command.
    The emission is throttled while waiting for a card and is ignored by BomberCat
    card peers.
2026-08-19 Add comprehensive documentation for BomberCat CLI
    - Introduced `protocol.md` to detail the line-based ASCII control protocol used for communication between the CLI and BomberCat devices.
    - Created `reference.md` for a complete command reference, including usage examples and expected outputs for each command.
    - Added `troubleshooting.md` to address common issues encountered while using the CLI, providing solutions and guidance.
    - Developed `usage.md` to outline end-to-end workflows for setting up and operating BomberCat devices in various configurations.
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2026-08-20 feat: add comprehensive and interactive pre-flight checks for testserver
    Introduces detailed and interactive pre-flight checks for `bombercat testserver run`
    and `smoke` commands. These checks proactively identify common setup issues
    such as missing `nfcgate-server` sources, Docker installation or daemon
    problems, incorrect socket permissions, and occupied host ports.
    Instead of cryptic `docker build` errors, the CLI now presents user-friendly,
    actionable panels with numbered fix steps and context-specific notes,
    significantly improving the developer experience. The `run.sh` script
    retains terse versions of these checks for direct invocation.
2026-08-20 fix: don't tell users to run newgrp when it isn't installed
    The Docker socket-permission panel of `testserver run` always printed
    `newgrp docker` as the step that applies the group to the current
    session. That binary ships in shadow-utils (`login` on Debian/Ubuntu),
    which trimmed installs and container images routinely leave out, so on
    a clean machine the panel could hand the user a command that does not
    exist — the one place where the fix has to be exact.
    The step is now chosen from what the machine actually has: `newgrp` if
    present, `sg docker -c "$SHELL"` as the equivalent from the same
    package, and otherwise a plain "log out and back in", stating that
    nothing can apply the group in pl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
2026-08-20 feat: drastically reduce server latency for NFCGate relay
    Implements Phases E and H of the latency optimization document (LATENCIA_OPTIMIZACION.md).
    Disables Nagle's algorithm and coalesces TCP writes to prevent ~40ms delayed-ACK stalls per hop, cutting transaction latency from ~13.5s to ~5s. Expensive per-frame hex dump and "Publish reached" logs are moved behind a new `--verbose` flag, saving an additional ~50-150ms on the hot path.
    These combined changes reduce total latency per transaction from ~13.5s to ~4.2s.
2026-08-20 feat: add tool to verify server latency patch on running instances
    The server latency optimizations (Phases E and H) drastically reduce transaction
    times. However, patching `server.py` on disk does not guarantee that a running
    Docker container (which bakes `server.py` into its image) is actually running
    the optimized code.
    This new `bombercat testserver verify` command and its backing script
    `verify_patch.py` connect to a live server instance and actively check its
    network behavior. It determines if the latency patch, specifically the coalesced
    TCP writes to avoid Nagle's algorithm stalls, is active. This provides a robust
    way to confirm the successful deployment of the optimizations on any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
2026-08-21 refactor(firmware): relocate firmware in a new repository
    [data.csv]
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
